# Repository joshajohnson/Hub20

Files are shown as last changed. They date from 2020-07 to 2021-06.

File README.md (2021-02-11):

# Hub20

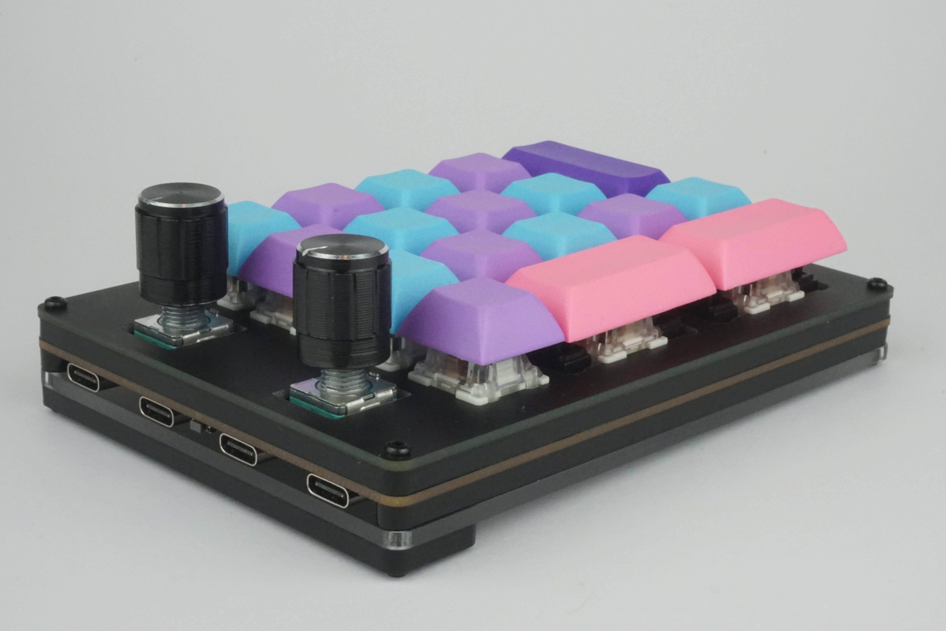
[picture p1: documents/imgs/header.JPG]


Hub20 is a numpad with a bunch of features you never knew you needed. They include:

- Left and Right handed layouts supported, along with a 4x5 1U grid enabling it to be used as a macropad.
- Two rotary encoders, enabling intuitive controls for a wide range of tools including CAD and photo / video editing.
- Inbuilt USB 2.0 Hub with Type-C connectors, allowing connection to other keyboards, memory sticks, wireless receivers and more!
- VIA and QMK compatibility, including a "macro" mode enabling the keys to be remapped on a host computer.
- 27 addressable RGB leds, including one under each key.

If this project looks familiar, it's because it contains all the best parts of [Hub16](https://github.com/joshajohnson/Hub16), with a few added extras.

## Project Status

Hardware is finalised and kits can be purchased from [Tindie](https://www.tindie.com/products/joshajohnson/hub20-programmable-macro-numberpad/).

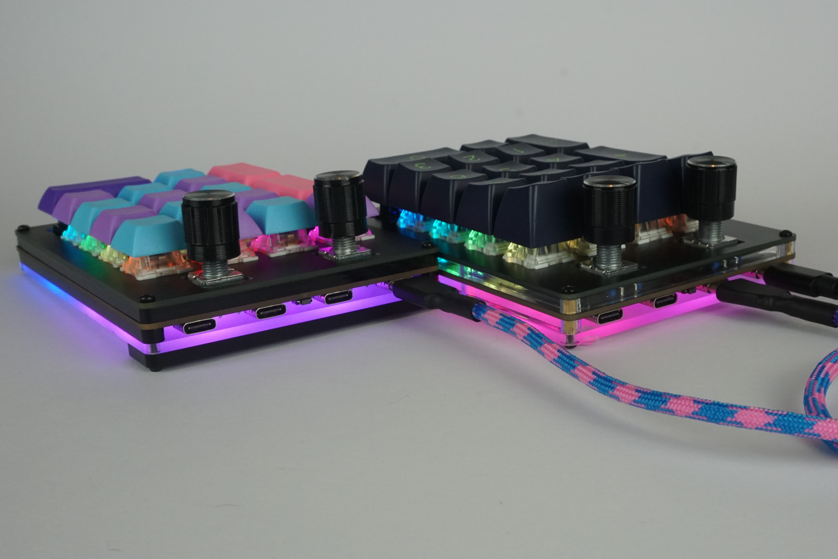
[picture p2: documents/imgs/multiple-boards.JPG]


## Getting Started Guide

- [Keyboard Assembly](documents/keyboard-assembly.md)
- [VIA Keymap Configuration](documents/via.md)
- [Macro Configuration](documents/macro.md)

## Detailed Info

- [Advanced Firmware / Software Configuration](documents/advanced-config.md)
- [PCB SMT Assembly Guide](documents/pcba.md)
- [Enclosure Manufacturing](documents/enclosure.md)

### Repo Contents

- `documents` contains all documentation and images for the project.
- `firmware` contains both the source and precompiled binaries for Hub20.
- `hardware` contains the KiCad design files for the keyboard.
- `josh-kicad-lib` is my personal KiCad parts library which contains many of the parts used.
- `scripts` contains a number of scripts used in the PCB design process.
- `mechanicals` contain the plate and case design for Hub20.
- `production` contains all the files required to produce the PCB. It also contains test scripts and jigs.
- `software` contains all the VIA config, along with template script to use Hub20 as a macropad with software on your computer.

### Notes on the USB Hub

The hub is a four port USB 2.0 Hub with Type-C connectors, aimed at allowing connection of keyboards, mice, memory sticks, wireless receivers, and other small devices (including a second Hub20!)  to your computer.

Due to cost and space constraints, the hub has some limitations. The hub **is not**:

- USB 3.x, Power Delivery, Thunderbolt, DisplayPort, etc compatible. 
- Designed to charge your phone quickly. Only 100mA is guaranteed per port.
- Designed to work with power hungry devices such as spinning hard drives.
- Guaranteed to provide full USB 2.0 speeds and performance on all ports.

Might you be able to charge your phone whilst copying files at full speed of a spinning hard drive over a long cable? Maybe. However Hub20 is a numpad first, USB hub second, so if you are looking for a high performance device I'd suggest picking up a dedicated USB hub and just using Hub20 as a numpad.

If you have any questions or comments please get in touch. I can be found on Discord as `_joshajohnson#9451`, [Twitter](https://twitter.com/_joshajohnson), email, or leave an issue or pull request on this repo.

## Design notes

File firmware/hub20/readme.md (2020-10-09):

# Hub20

Hub20 is a 20 key macro pad with an inbuilt USB 2.0 hub and dual rotary encoders. It can be configured to be a left / right hand numberpad, along with a 4x5 1u layout.

For more information regarding the keyboard, please visit the [Hub20 Website](https://www.joshajohnson.com/hub20-keyboard/) or [GitHub Repo](https://github.com/joshajohnson/Hub20).

* Keyboard Maintainer: [Josh Johnson](https://github.com/joshajohnson)
* Hardware Supported: Hub20 PCB (STM32F072)
* Hardware Availability: [Josh Johnson](https://www.joshajohnson.com/hub20-keyboard/)

Make example for this keyboard (after setting up your build environment):

    make hub20:default

See the [build environment setup](https://docs.qmk.fm/#/getting_started_build_tools) and the [make instructions](https://docs.qmk.fm/#/getting_started_make_guide) for more information. Brand new to QMK? Start with our [Complete Newbs Guide](https://docs.qmk.fm/#/newbs).

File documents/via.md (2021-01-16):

# VIA Keymap Configuration

`Hub20 was recently merged into VIA, so it should be automatically detected. If for some reason it is not, the below info should allow you to manually load the config file.`

- Open the settings tab in VIA, and enable "Show Design Tab".
- On the design tab, click "load" and select the [hub20.json](../software/via-hub20.json) file.
	- To download the json file, click through to the above link, select raw, copy all of the next into notepad or a similar text editor, and save as hub20.json.
- Hub20 should now be detected by VIA.

VIA is a great way to graphically configure your keyboard without going through the hassle of configuring build environments and poking around in the code.

## Install VIA

To use VIA, first [download and install](https://caniusevia.com/) the configuration software, and then plug in your keyboard. It should detect and show a graphic of Hub20 on your screen.

**Note: Hub20 ships with VIA by default, however if you have flashed a custom firmware on it you will need to ensure a VIA compatible keymap is on your board before continuing.**

## Configure Keys

From within VIA, you can easily configure keys as required. It allows not only the typical keys found on your keyboard, but media keys, macros, layer shifting to enable different functions per key, and even keys to control the LEDs installed in Hub20. It does not however allow you to configure the rotary encoder behaviour.

Due to the multiple layouts Hub20 allows, VIA allows you to toggle on / off the 2U keys required for it to be a left hand numpad. This can be done from the `layouts` tab in the top left of the screen. To configure Hub20 as a right hand numpad, enable split plus / enter / zero, and change the keymap as required. For the 2U keys, simply assign the same key to both keys in the pair.

## Configure Encoders

By default, the encoders are configured to volume up / down (left) and media next / prev (right).

Unfortunately, due to limitations in VIA the encoders are not visible or configurable. The best workaround at this time is to build a new VIA keymap with the encoder functions altered to suit your use case, flash this onto the board, and then configure the remainder of the keys in VIA. This can be done by following the below instructions:

- Follow the QMK [getting started guide](https://docs.qmk.fm/#/newbs_getting_started) to install the toolchain and configure your build environment.
- If you are reading this, the Hub20 firmware is not yet merged into QMK. Copy the `hub20` folder in `firmware` to `qmk_firmware/keyboards/hub20` before continuing.
- Open the `qmk_firmware/keyboards/hub20/keymaps/via/keymap.c` file in your preferred text editor.
- Locate the function `encoder_update_user`, and update the keycodes in `tap_code(KC_xxx)` to one from the [keycodes list](https://docs.qmk.fm/#/keycodes?id=basic-keycodes). If you use keycode not on the basic list, you may need to replace `tap_code` with `tap_code16`.
- With the changes made, save your new keymap, build, and flash the keymap to Hub20 with `make hub20:via:flash` run from the `qmk_firmware` directory.
- You should now see the encoders functioning as desired, and you can configure the remainder or your keyboard using VIA.

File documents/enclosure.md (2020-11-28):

# Enclosure Manufacturing

There are a number of ways the enclosure can be manufactured, and these options are outlined below:

All case files can be found in `mechanicals/1.0`.

By default, the enclosure has the below stackup:

```
--- PCB Plate, 1.6mm
--- Acrylic Upper, 4mm
--- Hub20 PCB, 1.6mm
--- Acrylic Mid, 4mm
--- Acrylic Lower, 3mm
  - Acrylic Incline, 3-4mm (optional)
```

You can however make a number of substitutions:

- Swap PCB plate for 3mm acrylic, and move upper 4mm acrylic to 3mm - note some switches may have reduced insertion depth into the PCB.
- Replace acrylic lower with FR4 PCB.
- 3d print parts instead of laser cutting or utilising PCBs for mechanical elements.
- Design your own! .step file can be exported from KiCad into you mCad tool of choice.

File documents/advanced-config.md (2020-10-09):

# Advanced Firmware and Software Configuration

This section details how Hub20 works, and how you can modify it to suit your needs.

If you are simply looking for into on how to get up and running, the [VIA](via.md) and [Macro](macro.md) documentation may be better suited.

## Summary

The macro functionality of Hub20 is quite unique, as it moves control over what key is detected by the host computer from the keyboard to the computer itself, which enables a whole new level of control. Examples of functionality enabled by this include:

- Dynamically assigning keys pressed depending on open application, e.g. encoder changing zoom in Photoshop, but zooming timeline in Premiere.
- Accessing low level functions, such as directly bringing a given application to the foreground without tabbing through open windows.
- Running shell commands without opening a shell and playing back key sequences.
- Any other feature that your software (AutoHotKey, Karabiner-Elements, Autokey) provides an interface for.

## Theory of Operation

- Hub20 works by presenting a uniquely identifiable key to your computer, which can be intercepted by a intermediate layer of software on your computer, and can then be processed as required.
- This works by "wrapping" a normal key press with a modifier key to create a unique key, just like pressing SHIFT changes the key shown on your screen when pressed in conjunction with a key on your keyboard.
- However, as CTRL, SHIFT, ALT etc are commonly used they would not be very helpful to generate a unique key, so we instead use F13 - F24 as most keyboards do not have these, but are still valid keycodes.
- To achieve this, when you press a key, Hub20 first sends a modifier key (e.g. F23) before pressing down the key you touched. Upon release of your key, it releases the modifier, allowing the computer to pick up that Hub20 has pressed a key.
- **NOTE** macOS instead uses the VID:PID of your device to uniquely identify Hub20, however the high level concept outlined above still applies.

## Firmware Configuration

The default configuration can be easily changed, allowing for further customisation of the board. Examples of what can be done include:

- Holding down a key / encoder button results in different keys being sent when rotating the encoder, effectively doubling (or tripling etc) the number of encoders on the board.
- Extending the number of macro keys by having multiple layers of unique keys, accessed by the bottom row of keys being dedicated to shifting layers.
- Building the macro configuration with VIA enabled, allowing LEDs to be customised from the VIA GUI instead of tapping keys to change the mode and colour.

Key sections of the code and their function are outlined below:

| Section | Description |
| --- | --- |
| `#define KC_WRAP` | If you have more than one Hub20 connected, change the wrapping function key to differentiate boards. |
| `const uint16_t PROGMEM keymaps` | This section is where the keymaps live, and if you want to alter the behaviour of a key this is the place to do it. |
| `void encoder_update_user` | Want to change what rotating an encoder does? If so this is the place to look. |
| `bool process_record_user` | Every time a non [quantum](https://docs.qmk.fm/#/keycodes?id=quantum-keycodes) key is pressed, it will be run throught this section, and is the place to implement custom functions such as sending custom strings, turning on / off a mouse shaker, or any custom action you want when a key is pressed. |
| `void td_ctrl` | To work around the limitations of `process_record_user` this function is required to ensure the layer toggle key is wrapped when sent to the host computer. If you don't want to use tap dance, or are okay having a dedicated key to toggling layers, this can be removed. |

## Software Configuration

Due to the different software being required for each OS, and the varying levels of options each tool provides, it's challenging to make any specific recommendations for ways to customise the software running on your host PC. With this said, I would strongly suggest looking at the `hub20-example.ahk` script which is an obfuscated version of what I use at work every day, along with the documentation of your chosen scripting tool to see what is possible, and think how it may help your day to day workflow. Below are some examples of what people have used their Hub16 / Hub20 to automate:

- Running complex shortcuts with a single key.
- Placing common shortcuts (enlarge / shrink) on the encoders to ease adjustment.
- Pulling a specific windows to the foreground with a single tap.
- Dedicated keys for video conference muting, sharing screens etc.
- Automating filling out of repetitive forms (e.g. the Auspost customs declaration...)
- Having emoticons or emoji a single keystroke away. (•◡•) /
- Alternate input for racing / flight simulators.

If you come up with a novel use case, I'd be very interested to hear about it so please get in touch!

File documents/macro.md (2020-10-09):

# Macro Configuration

Hub20 can also be used with software on your computer to enable powerful, context aware macros to be run.

This works by sending uniquely identifiable keys to your computer which are picked up by software, which can then map those keys as required. As such, this requires the correct firmware to be loaded onto Hub20, and software to be installed on your computer.

## Firmware

Hub20 does not ship with the macro firmware preinstalled, but is easily flashed onto your board.

MechMerlin has [a great video](https://youtu.be/VR53Wo9Z960) on the process, so I will highlight the Hub20 specific configurations / settings.

- When selecting the file to flash, use `firmware/binaries/hub20_macro.bin`.
- There is no need to select the microcontroller before flashing the board.
- The reset button can be found between the USB connectors on the back of the board, or by holding down the top right button and depressing the left encoder.

The default configuration for the keyboard is shown below:

```
------------------
|  ENC1   ENC2   |  ENC1:Clockwise: u
| a   b   c   d* |  ENC1:Anticlockwise: v
| e   f   g   h  |  ENC2:Button: w
| i   j   k   l  |  ENC2:Clockwise: x
| m   n   o   p  |  ENC2:Anticlockwise: y
| q   r   s   t  |  ENC2:Button: z
------------------
```

\* Once flashing the macro layout you may notice that holding or tapping the top right key quickly may not result in a key being sent. This because if you double tap that key, it will bring you to a configuration layer on the keyboard which allows you to control the LEDs and reset the keyboard.  Double tapping the same key will return you to the base layer. The keymap for this configuration is shown below:

```
                Reset,   _______,
 RGB On/Off,  RGB Prev,  RGB Next,       Home,
    _______,  Bright +,  BRIGHT -,    _______,
    _______,     Hue +,     Hub -,    _______,
    _______,     Sat +,     Sat -,    _______,
    _______,   _______,   _______,    _______,

```

## Software

### Windows

- Download and install [AutoHotKey](https://www.autohotkey.com/).
- Copy the example script from `software/hub20-template.ahk` into a folder of your choice.
- For the script to run at startup, I strongly suggest placing a shortcut to the above file in `%APPDATA%/Roaming/Microsoft/Windows/Start Menu/Programs/Start-up`.
- Configure the script to suit your use case, ensuring to restart the AHK script after each change, otherwise it will not use the latest changes.

### macOS

- Install [Karabiner-Elements](https://karabiner-elements.pqrs.org/docs/getting-started/installation/).
- Copy the example script from `software/karabiner-hub20.json` to your local `~.config/karabiner` folder.
- Configure keybindings as required.

### Linux

- Whilst it's slightly more painful and buggy to configure and use on Linux, the below is the best configuration I've got to work. PRs are very much welcome for improvements to this.
- Install AutoKey from [here](https://github.com/autokey/autokey/wiki/Installing#debian-and-derivatives), as the apt-get version is broken.
- Create a file in your home directory with the name `.Xmodmap` and the following contents

    ``` bash
    keycode 202 = Hyper_R
    add mod3 = Hyper_R
    ```

- Update xmodmap with `xmodmap ~/.Xmodmap` and then confirm that `mod3` has been updated by entering `xmodmap` in your shell and looking for `mod3 Hyper_R (0xca)`.
- Then add it to your ```~./bashrc```, as this will allow the keyboard to work **only after a shell is opened by the user**. A PR to resolve this would be very welcomed.
- Load the AutoKey files found in `software/hub16` and it should work.
    - Note: you may need to make a new folder from within Autokey, then copy your files in as it is particular about locating new files.
- You will also need to configure AutoKey to start at boot, which can be done from `Edit -> Preferences`.
- For volume and media control as configured in my example code, [playerctl](https://github.com/altdesktop/playerctl) and ```alsa-utils``` must be installed.

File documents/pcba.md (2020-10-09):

# PCB SMT Assembly Guide

I highly recommend assembling this board using solder paste, a stencil, and a reflow oven. If you don't have access to a reflow oven, a hot air gun will also get the job done. 

- Gerbers can be found in `production/1.0-prod/gerbers.zip` folder, and can be uploaded to your favourite PCB manufacturer.
- Most PCB houses will generate the solderpaste stencil from your copper layer, which can cause issues. As such I recommend uploading the stencil separately to ensure the apertures are as per the design files.
- The bill of materials can be found at `production/1.0-prod/bom.csv` and contains part numbers for all components on the board. DigiKey and LCSC part numbers are provided where available, however some parts such at the USB connectors, reverse mount LEDs, and USB hub may only be available at one or neither of the suppliers.
- The "Human PnP" file is located at `production/1.0-prod/assembly.html`, and will be very helpful in assembling the board.

With the board assembled and reflowed, it is time to power it up and flash the firmware.

- Before powering up, measure between 5V, 3V3 and GND to ensure there are no shorts. The capacitors either side of the linear regulator are an easy place to measure.
- Upon plugging the board in, you should see the PWR led turn on, and the USB hub enumerate. The STM32 microcontroller will not be detected at this time.
- To flash the firmware, run `make hub20:default:flash` from within your `qmk_firmware` folder. Reset the board using the reset button, and you should see `dfu-util` flash the board.
- Confirm all keys work by shorting the switch contacts with tweezers and looking for an output from the board, and confirm the USB hub works by plugging a device into each port and checking for enumeration. Ensure you flip the USB connector and test all the ports with it in the other orientation as well.

If the board does not work, common issues include:

- Shorts / opens on the QFN and USB footprints.
- Crystal for the USB hub not being soldered down correctly.
- Diodes being installed backwards.
- LEDs damaged due to moisture ingress / excessive heat during reflow.
- Shorts on the resistor networks.

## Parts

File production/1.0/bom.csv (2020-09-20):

Qty | Reference(s) | Value | Footprint | MPN | DigiKey | LCSC | Manufacturer | DNP | Notes | Substitue Allowed?
44 | C1, C11, C12, C13, C15, C16, C17, C21, C22, C23, C24, C25, C26, C27, C29, C30, C31, C33, C35, C36, C37, C38, C39, C4, C40, C42, C43, C46, C47, C48, C49, C5, C50, C51, C52, C53, C56, C58, C59, C6, C60, C7, C8, C9 | 100n | Capacitor_SMD:C_0603_1608Metric | CL10B104KB8NNNC | 1276-1000-1-ND | C1591 | Samsung Electro-Mechanics |  |  | Y - X5R or better
8 | C10, C19, C28, C32, C34, C54, C55, C57 | 1u | Capacitor_SMD:C_0603_1608Metric | CL10A105MP8NNNC | 1276-1866-1-ND | C29936 | Samsung Electro-Mechanics |  |  | Y - X5R or better
3 | C14, C20, C41 | 10u | Capacitor_SMD:C_0603_1608Metric | CL10A106MP8NNNC | 1276-1871-1-ND | C85713 | Samsung Electro-Mechanics |  |  | Y - X5R or better
1 | C18 | 4u7 | Capacitor_SMD:C_0603_1608Metric | CL10A475MP8NNNC | 1276-1905-1-ND | C307473 | Samsung Electro-Mechanics |  |  | Y - X5R or better
2 | C44, C45 | 15p | Capacitor_SMD:C_0603_1608Metric | CL10C150JB8NNNC | 1276-1296-2-ND | C1644 | Samsung Electro-Mechanics |  |  | Y - NP0 / C0G
1 | D1 | 1N4148 | Diode_SMD:D_SOD-123 | 1N4148W-7-F | 1N4148W-FDICT-ND | C83528 | Diodes Inc |  |  | Y - Any 1N4148
22 | D10, D11, D12, D13, D14, D16, D18, D19, D20, D21, D22, D24, D25, D26, D27, D28, D29, D4, D5, D6, D7, D8 | 1N4148 | Diode_SMD:D_SOD-123 | 1N4148W-7-F | 1N4148W-FDICT-ND | C83528 | Diodes Inc |  |  | Y - Any 1N4148
7 | D15, D17, D2, D23, D3, D30, D9 | WS2812B | LED_SMD:LED_WS2812B_PLCC4_5.0x5.0mm_P3.2mm | WS2812B | 1528-1104-ND | C114586 | Worldsemi |  | Must be black | N
20 | D31, D33, D34, D35, D36, D37, D38, D39, D40, D41, D42, D43, D44, D45, D46, D47, D48, D49, D50, D51 | SK6812MINI-E | josh-keyboard:DUMMY_SK6812MINI-E | SK6812MINI-E |  |  | Shenzhen LED Colour |  | Similar to: https://www.alibaba.com/product-detail/Best-selling-SK6812-MINI-E-1500pcs_62354369359.html | N
1 | D32 | LED | LED_SMD:LED_0603_1608Metric | OSK40603C1E |  | C268294 | OptoSupply |  |  | Y - Any Pink / Purple
1 | F1 | 1A | josh-passives-smt:Fuse_0805_2012Metric | 0805L100WR | F2774CT-ND | C80270 | Littelfuse |  |  | Y - 1A hold / >1.5A trip
3 | F2, F3, F4 | 500mA | josh-passives-smt:Fuse_0805_2012Metric | 0805L050WR | F2772CT-ND | C207022 | Littelfuse |  |  | Y - 500mA hold / 1A trip
5 | FB1, FB2, FB3, FB4, FB5 | 600R | josh-passives-smt:Ferrite_Bead_0603 | BLM18KG601SN1D | 490-5258-1-ND | C85833 | Murata |  |  | Y - 600R, > 1A current
4 | H1, H2, H3, H4 | M3 | MountingHole:MountingHole_3.2mm_M3 |  |  |  |  | DNP
4 | J1, J2, J3, J4 | USB_C_Receptacle_USB2.0 | josh-connectors:USB_C_U262-161N-4BVC11 | U262-161N-4BVC11 |  | C319148 | XKB Enterprise |  | Cannot source from DigiKey | Y - Footprint / pinout compatiable
1 | JP1 | LED | Jumper:SolderJumper-2_P1.3mm_Bridged_RoundedPad1.0x1.5mm |  |  |  |  | DNP
1 | LOGO1 | Josh-Details | josh-logos:josh-details |  |  |  |  | DNP
1 | LOGO2 | Board-Title | josh-logos:board-title |  |  |  |  | DNP
1 | LOGO3 | Josh-Logo | josh-logos:josh-johnson-logo-11x2 |  |  |  |  | DNP
1 | LOGO5 | OSHW | josh-logos:OSHW-Logo2_9.8x8mm_Mask |  |  |  |  | DNP
2 | MX1, MX2 | 2U | josh-keyboard:MXOnly-2U-NoLED-3PIN |  |  |  |  | DNP
4 | MX3, MX4, MX5, MX6 | 2U | josh-keyboard:MXOnly-2U-ReversedStabilizers-NoLED-3PIN |  |  |  |  | DNP
1 | Q1 | DTC123J | Package_TO_SOT_SMD:SOT-23 | DTC123JKAT146 | DTC123JKAT146CT-ND | C111724 | ROHM Semicon |  |  | Y - Any DTC123J
1 | Q2 | BSS138 | Package_TO_SOT_SMD:SOT-23 | BSS138 | BSS138CT-ND | C52895 | ON Semiconductor |  |  | Y - Any BSS138
1 | R10 | 649R | Resistor_SMD:R_0603_1608Metric | MCR03ERTF6490 | RHM649CFCT-ND | C403314 | Rohm Semiconductor |  | LCSC: Substitute PN | Y - Same spec
3 | R14, R2, R3 | 5K1 | Resistor_SMD:R_0603_1608Metric | CR0603-JW-512ELF | 118-CR0603-JW-512ELFCT-ND | C14677 | Bourns |  | LCSC: Substitute PN | Y - Same spec
1 | R4 | 100K | Resistor_SMD:R_0603_1608Metric | CR0603-JW-104ELF | CR0603-JW-104ELFCT-ND | C100048 | Bourns |  | LCSC: Substitute PN | Y - Same spec
5 | R5, R6, R7, R8, R9 | 10K | Resistor_SMD:R_0603_1608Metric | CR0603-JW-103ELF | CR0603-JW-103ELFCT-ND | C144116 | Bourns |  | LCSC: Substitute PN | Y - Same spec
2 | RN1, RN2 | 10K | Resistor_SMD:R_Array_Convex_4x0603 | RAVF164DJT10K0 | RAVF164DJT10K0CT-ND | C107374 | Bourns |  | LCSC: Substitute PN | Y - Same spec
1 | RN3 | 10K | Resistor_SMD:R_Array_Convex_4x0603 | RAVF164DJT10K0 | RAVF164DJT10K0CT-ND | C107374 | Bourns |  | LCSC: Substitute PN | Y - Same spec
1 | SW1 | EVQPUL | josh-buttons-switches:Panasonic_EVQPUL_EVQPUC | EVQ-PUL02K | P10853SCT-ND | C397351 | Panasonic |  | LCSC: Substitute PN | Y - Same footprint
20 | SW10, SW11, SW12, SW14, SW15, SW16, SW17, SW18, SW19, SW2, SW20, SW21, SW22, SW23, SW3, SW4, SW5, SW6, SW8, SW9 | MX_RGB | josh-keyboard:MX_KEYSWITCH_RGB |  |  |  |  | DNP
2 | SW13, SW7 | EC11 | josh-buttons-switches:RotaryEncoder_Alps_EC11E-Switch_Vertical_H20mm_CircularMountingHoles | PEC11L-4120F-S0020 | PEC11L-4120F-S0020-ND |  | Bourns | DNP | Similar to: https://www.aliexpress.com/item/32839106848.html | Y - 20 pulse per revolution
1 | U1 | AP2112K-3.3 | Package_TO_SOT_SMD:SOT-23-5 | AP2112K-3.3TRG1 | AP2112K-3.3TRG1DICT-ND | C51118 | Diodes Incorporated |  |  | N
4 | U2, U6, U7, U8 | USBLC6-2SC6 | Package_TO_SOT_SMD:SOT-23-6 | USBLC6-2SC6 | 497-5235-1-ND | C7519 | STMicroelectronics |  |  | N
1 | U3 | STM32F072C8Tx | Package_QFP:LQFP-48_7x7mm_P0.5mm | STM32F072C8T6 | 497-17359-1-ND | C80488 | STMicroelectronics |  |  | N
1 | U5 | CY7C65632-28LTXCT | josh-dfn-qfn:QFN-28-1EP_5x5mm_P0.5mm_EP3.35x3.35mm_ThermalVias | CY7C65632-28LTXCT | 428-3156-1-ND | C466886 | Cypress Semiconductor |  |  | N
1 | Y1 | 12MHz | josh-oscillators:Crystal_SMD_3225-4Pin_3.2x2.5mm | ABM8-12.000MHZ-12-B1U-T | 535-14962-6-ND | C164041 | Abracon LLC |  | LCSC: Substitute PN | Y - 12 MHz, 10/12pF

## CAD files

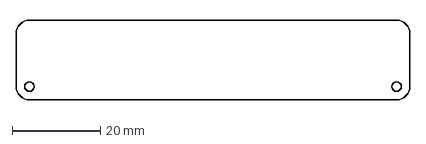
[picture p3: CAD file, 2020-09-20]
mechanicals/1.0/Hub20-riser.dxf
89.0 x 18.0 mm

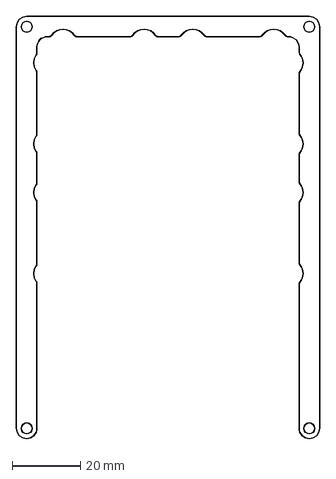
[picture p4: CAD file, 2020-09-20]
mechanicals/1.0/Hub20-mid.dxf
89.0 x 124.0 mm

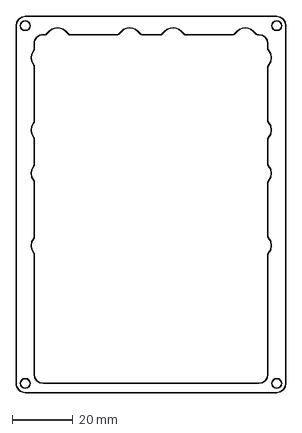
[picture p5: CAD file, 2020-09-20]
mechanicals/1.0/Hub20-top.dxf
89.0 x 124.0 mm

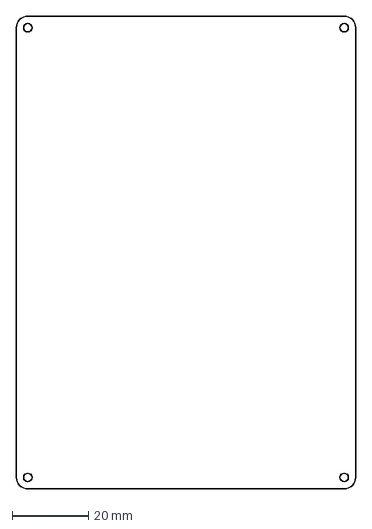
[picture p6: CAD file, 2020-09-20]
mechanicals/1.0/Hub20-bottom.dxf
89.0 x 124.0 mm

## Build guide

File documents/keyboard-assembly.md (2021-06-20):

# Assembly Instructions

Before assembling the board, ensure you have all of the required parts.

* Top cover / Plate PCB
* Assembled keyboard PCB
* Laser cut acrylic - 4 pieces
* 2 * Rotary encoders (20mm recommended)
* 2 * Rotary encoder knobs
* 4 * 4mm M2 cap head bolts (bare-bones 8 * 4mm)
* 4 * 8mm M2 cap head bolts (plus 2 * 10mm M2 if using bottom riser)
* 4 * 8mm female threaded standoffs (bare-bones 10mm)
* 4 * Rubber feet (optional)
* 17-20 * Cherry MX Key Switches (not shown) (3 pin switches required for 2U keys)
* 17-20 * 1U Cherry MX Keycaps (not shown)
* 0-3 * Screw In Stabilisers (not shown)

You will also require the following:

* Soldering iron and solder
* 1.5mm allen key
* Dielectric Grease (to lube stabilisers)

If you are assembling the bare-bones version, follow the below steps but omit the acrylic parts.

Please ensure you remove the protective paper off all acrylic parts before starting.
If there are rough edges on the PCB, feel free to smooth down with sandpaper or a file.

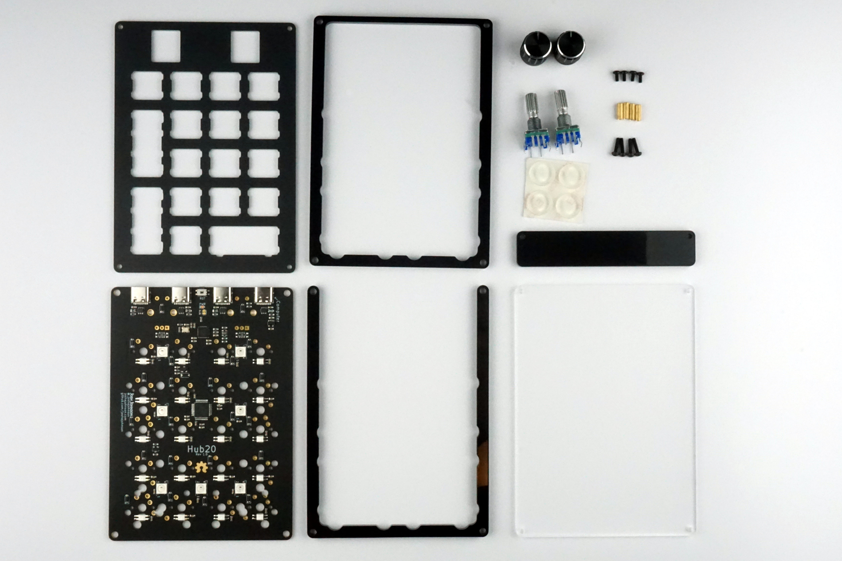
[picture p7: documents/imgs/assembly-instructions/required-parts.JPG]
Parts Required


### Step 0: Check PCB

Whilst we do our best to ensure the PCBs work, there may be issues that slip through QC or the boards may be damaged in freight. As such you should test the PCB before continuing.

Boards come preloaded with VIA for testing, and using their "Key Tester -> Test Matrix" option is the easiest way to ensure the board works. `If VIA does not automatically detect your HUb20, follow ` [these](via.md) `instructions to load the config file so the board can be detected.`

**Check the key switches by using tweezers to short the key switch pins together.**  
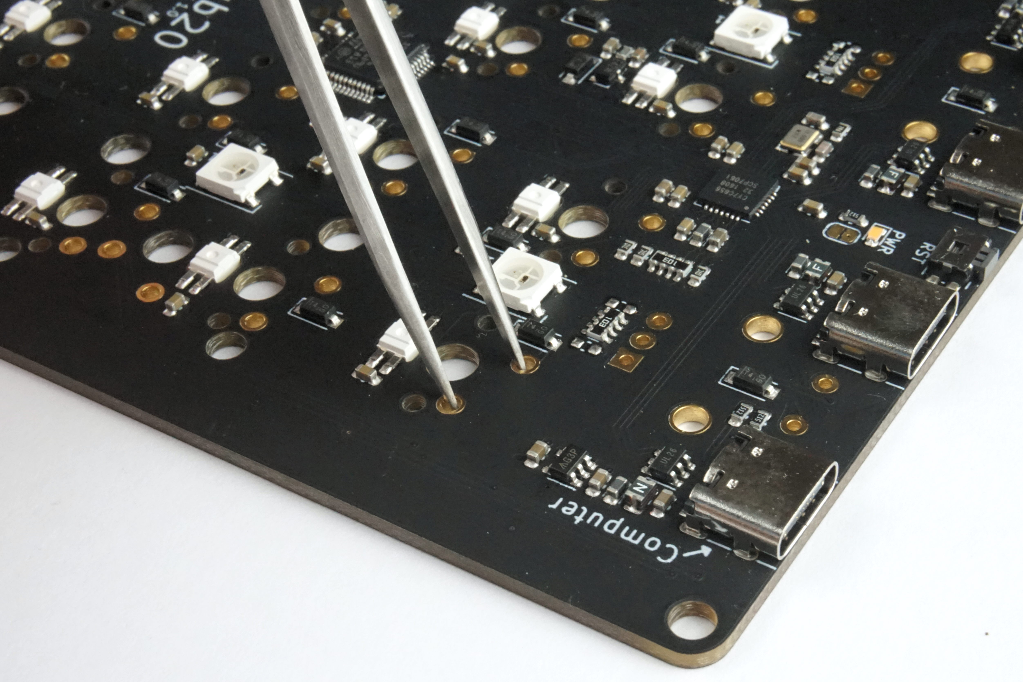
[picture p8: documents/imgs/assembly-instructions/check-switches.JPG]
Checking Keys


**Check the encoders by placing encoder against pins and rotating.**  
You may need to angle the encoder down to ensure it has good contact. Also test the encoder switch by shorting the two pins towards the top of the PCB.

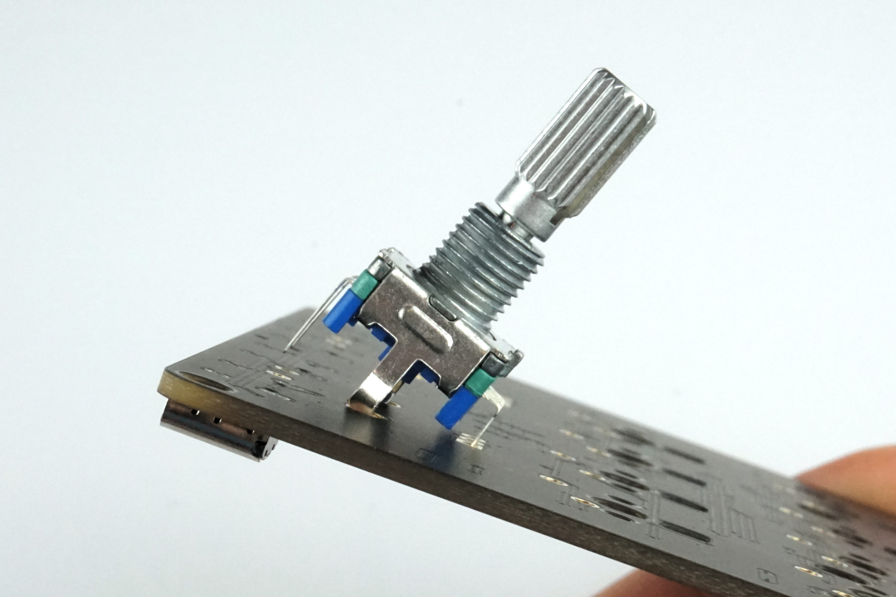
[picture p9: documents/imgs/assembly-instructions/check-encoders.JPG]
Checking Encoders


**Check the USB hub by connecting a device to each port, with cable orientated in both orientations.**  
You should see a your device appear on each port.

### **If there are any issues getting the above to work, please get in touch before proceeding to assemble the board.**

### Step 1: Solder Encoders

The first step in assembling your Hub20 is to solder the rotary encoders. Ensuring the pins are straight, insert the rotary encoders and tack in two pins on opposite corners.
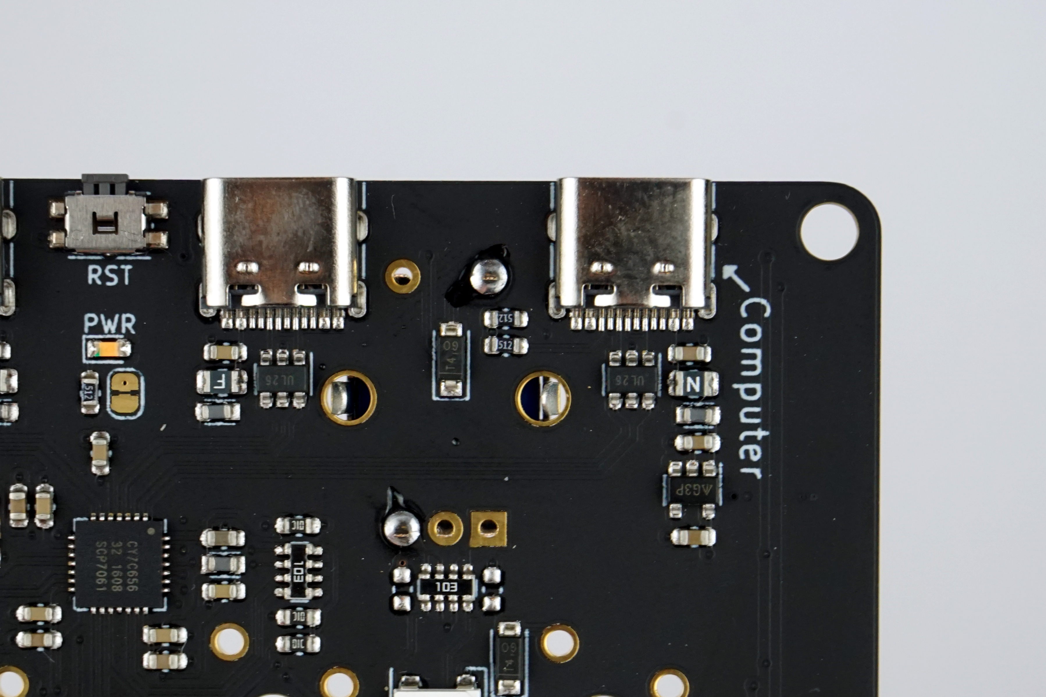
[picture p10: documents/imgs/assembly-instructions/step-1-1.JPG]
Tacking encoder


Before soldering in the remaining pins, ensure the encoder is perpendicular. If adjustments are required, heat one of the solder joints and gently push the encoder until it is seated. Repeat until you are satisfied with how the encoders look. (Hint: you shouldn't be able to see the encoder hiding on the other side of the board!)
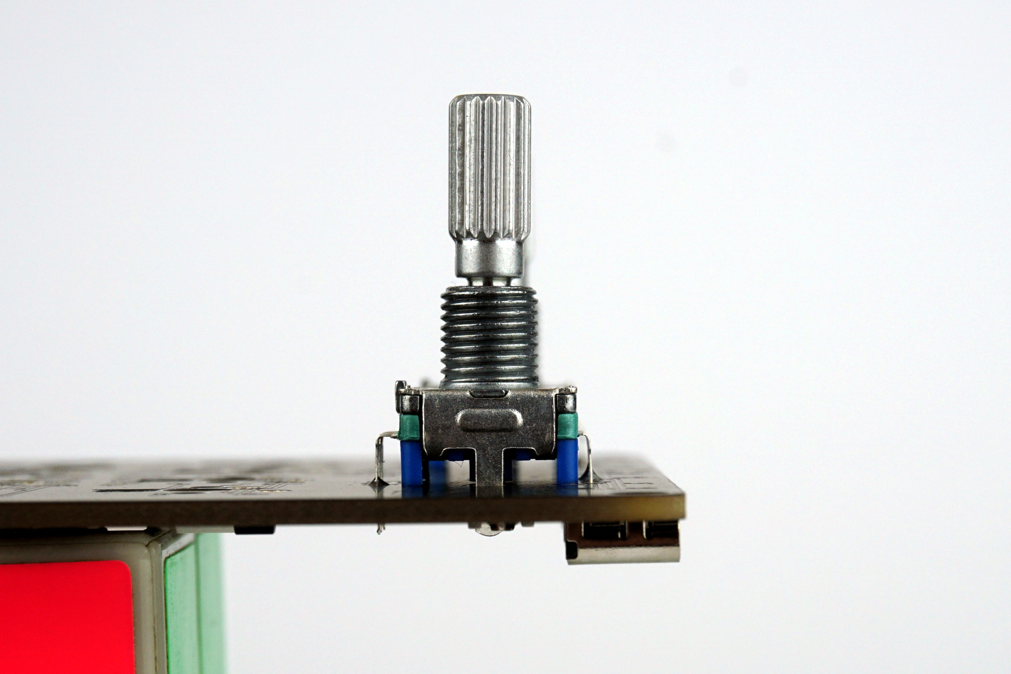
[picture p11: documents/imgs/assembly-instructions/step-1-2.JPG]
Checking encoder is square


With your encoders in nice and square, solder the rest of the pins. I'd suggest soldering all of the smaller pins and checking everything is still square before soldering in the mechanical legs as they make it very hard to move the encoder.
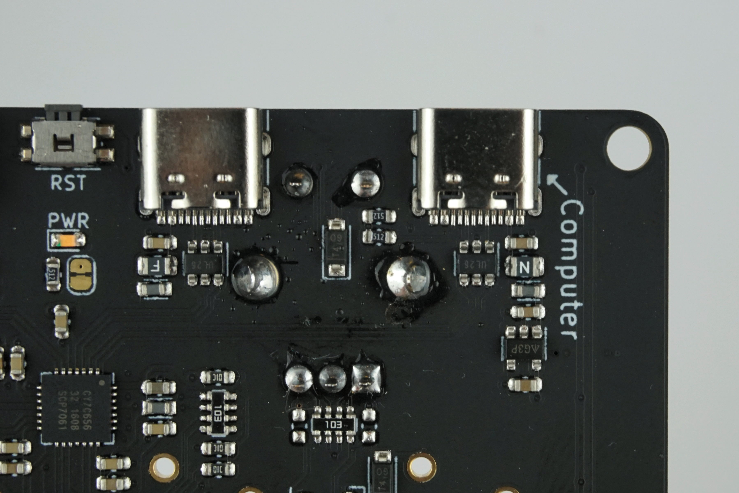
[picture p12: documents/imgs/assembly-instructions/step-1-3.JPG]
Soldering all pins


### Step 2: Install Stabilisers

Stabilisers are required for all of the "2U" switches, as they prevent the keys from wobbling. Before installing, I highly recommend you [lubricate your stabilisers](https://youtu.be/cD5Zj-ZgMLA) as otherwise they will rattle. If you don't want to go through the hassle of the above video, just make sure you [lube the wires](https://youtu.be/cD5Zj-ZgMLA?t=185) as this is the largest contributor to noise.

Depending on if you configure the board as a left or right numpad (or a 4x5 grid, in which case you can skip this) you will need to place the stabilisers in different locations. Left image is for the left numpad config, right image is for the right numpad configuration.

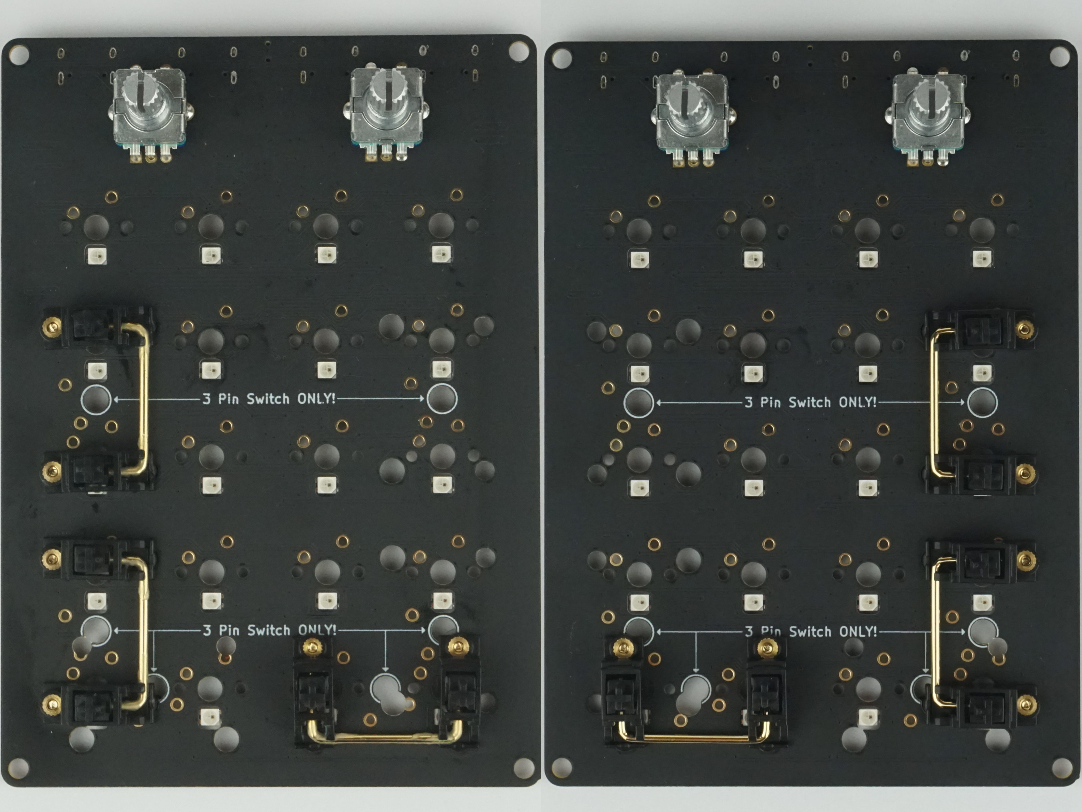
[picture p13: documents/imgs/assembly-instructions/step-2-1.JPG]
Stabiliser locations


When installing the stabilisers, ensure you use the non-conductive washers which are included. This prevents the screws from contacting with the PCB and causing shorts or damaging traces.

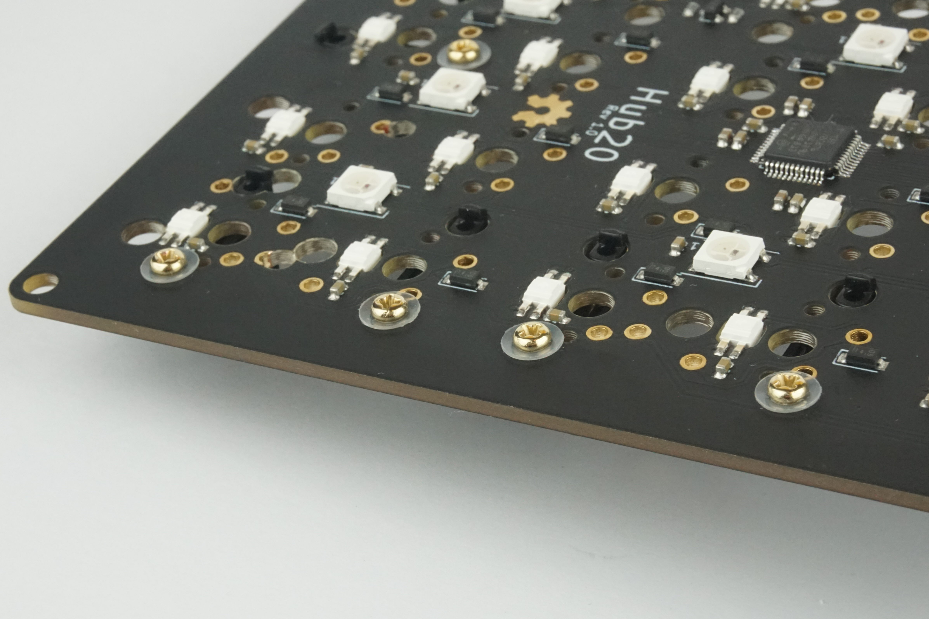
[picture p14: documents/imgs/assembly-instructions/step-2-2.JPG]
Ensure you use non-conductive washers


### Step 3: Assemble upper case

With the encoders soldered and stabilisers installed, the next step is to thread the standoffs into the shorter screws through the top plate. Just do this up touch tight, as we may need to loosen it later.
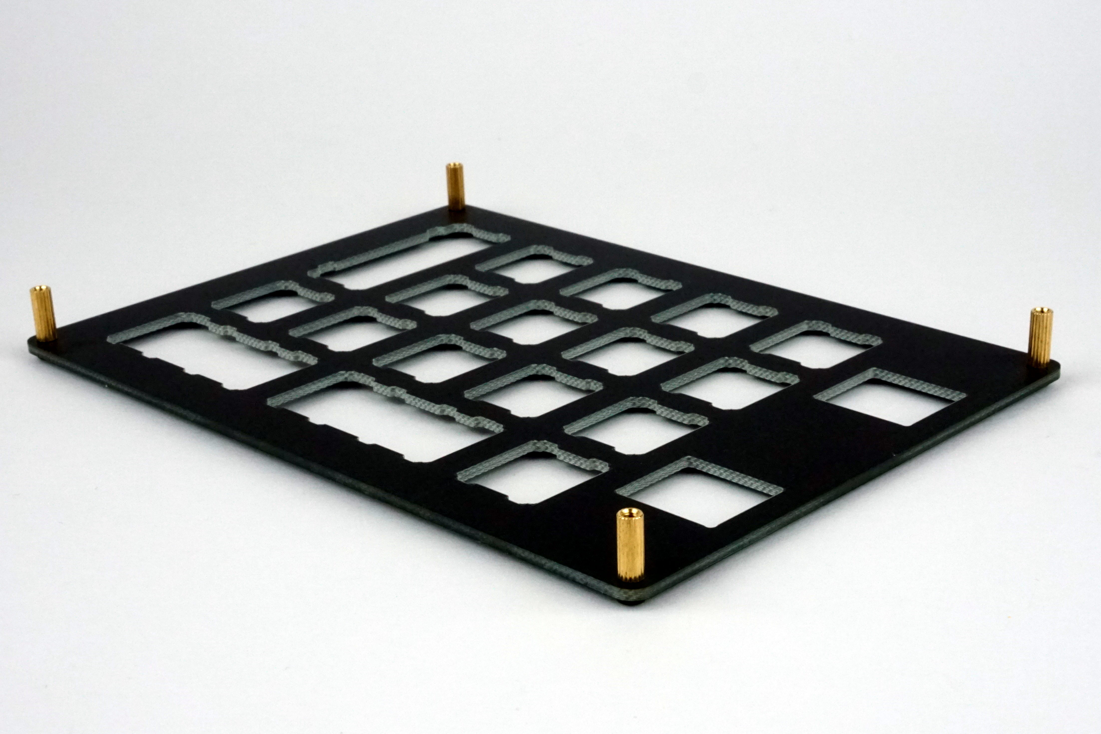
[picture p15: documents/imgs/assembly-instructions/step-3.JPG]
Bottom plate assembly


### Step 4: Add "O" shaped spacer

Add the "O" shaped spacer, ensuring the cutouts are towards the bottom as they provide clearance for the stabilisers.
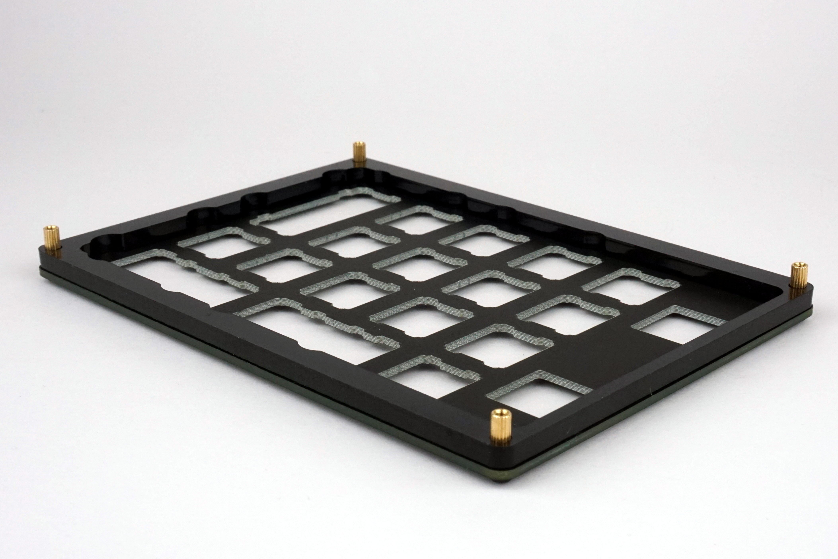
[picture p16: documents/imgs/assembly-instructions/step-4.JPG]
Adding U shaped spacer


### Step 5: Place PCB into case, and solder switches

Place the PCB into the case, followed by a switch in each corner to hold it in place.
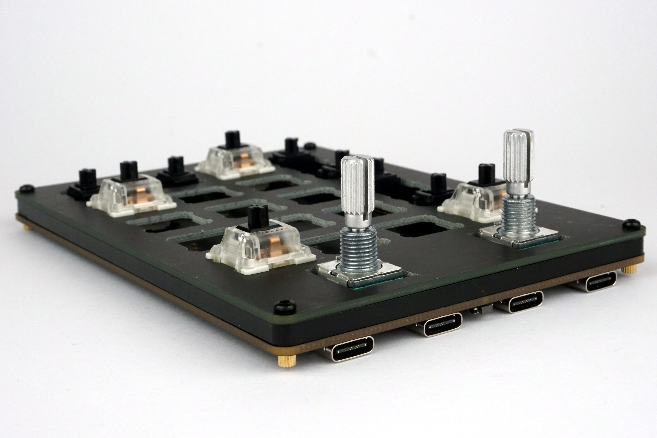
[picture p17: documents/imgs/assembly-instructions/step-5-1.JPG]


Tack one pin from each switch in place to keep everything together, and check for gaps along the side of the case. If there are gaps, press the case together whilst heating the soldered pin and the case should squish together. Once everything is flush, add the remaining keys and solder.
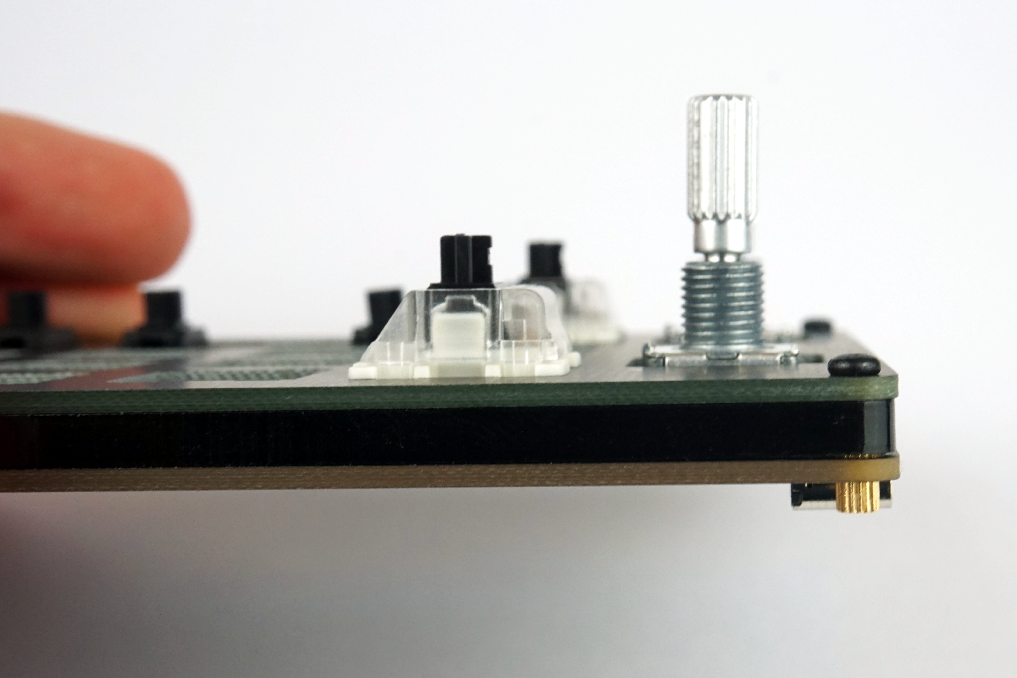
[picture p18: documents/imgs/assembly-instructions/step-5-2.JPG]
Checking edges are aligned


### Step 6: Add "U" shaped spacer

Place the remaining "U" shaped acrylic spacer on top of the PCB, ensuring the open end faces towards the USB connectors.
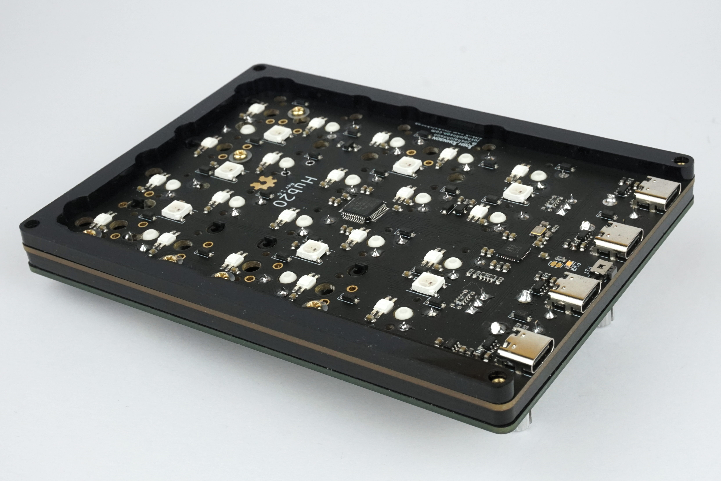
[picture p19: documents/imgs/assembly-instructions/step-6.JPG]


### Step 7: Add bottom plate and remaining screws

When installing the bottom plate, if you choose to use the small riser you will need to use the 10mm bolts instead of the 8mm bolts that are used at the bottom of the case. It can help to have the standoff flush to the acrylic to get the bolt started (please pretend the standoff is flush in this photo, I couldn't get a good photo of it...).
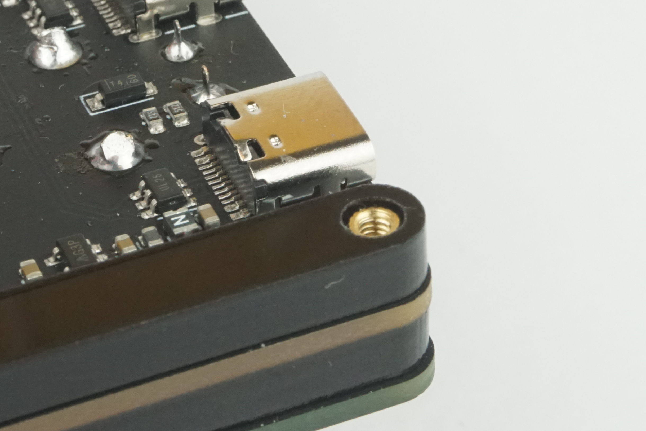
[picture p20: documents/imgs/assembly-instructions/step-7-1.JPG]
Spacer sitting flush


After installing the bottom plate and screws, snug all of the bolts up and your Hub20 is now assembled!
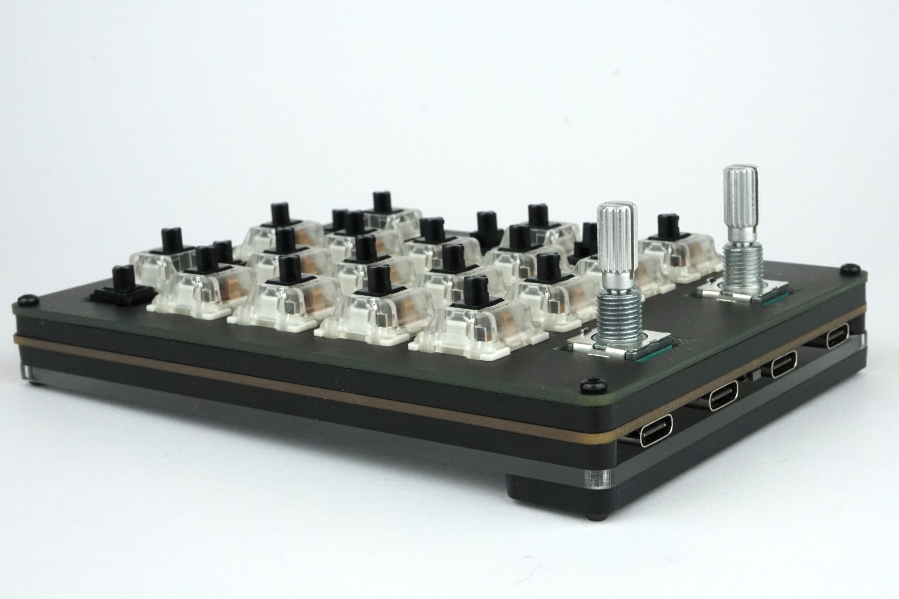
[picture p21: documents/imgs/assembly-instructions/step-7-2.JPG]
Bottom plates assembled


### Step 8: Add keycaps and encoder knobs

Finally, fit your keycaps of choice and the encoder knobs, and you are done! Enjoy :D
Adding knobs and keycaps

## Disabling Power LED

If you find the power LED annoying and would like to disable it, cut the jumper near the USB ports. The easiest way to do this is to run a knife down the thin black gap between the two large pads. The LED can be re-enabled by soldering the jumper shut.

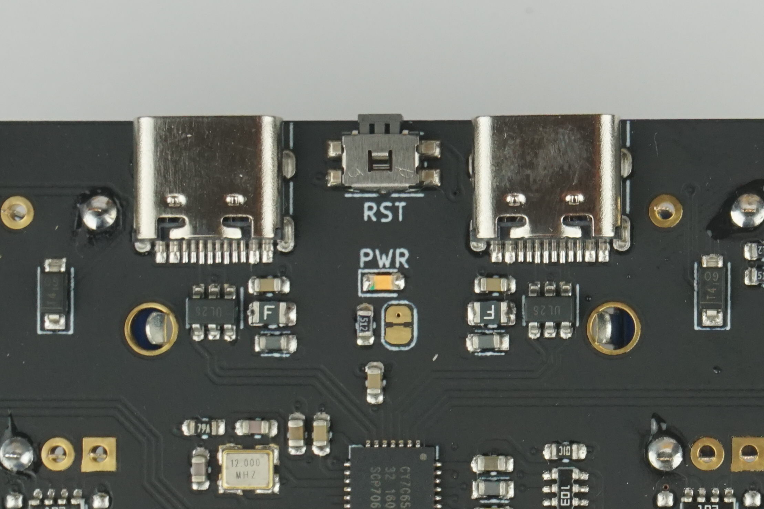
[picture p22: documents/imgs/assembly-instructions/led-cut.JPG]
Cutting trace for power LED


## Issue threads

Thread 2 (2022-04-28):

How simple would it be for a somewhat tech-aware beginner to mod this with a third encoder?

arrowtype, 2022-04-28:
Hi Josh, this is an incredibly cool project! It’s _so_ close to being my dream numpad, but I would love to find (or make?) something with _three_ encoders.

I’m a total noob in this area, but very curious how big a challenge it might be to learn the requisite software & processes to add a third encoder to the system.

My main reason for seeking three encoders is the software I use to kern fonts. It would be amazing to use one encoder to step through a list of letter pairs, a second to make large-grained adjustments, and a third to make fine-grained adjustments. I’ve tried to process with a two-encoder board, and it’s very nice, but I wish I didn’t have to toggle modes to go from large to small adjustments.

Thanks for making and sharing this project!

(PS: Apologies if this is the wrong place to ask, but I figure at least others might come across it if they search for a similar question.)

joshajohnson, 2022-04-28:
Hey Stephen,

Adding a third encoder would be easy if it wasn't for the USB hub being in the way.

The below image shows the two encoders on either side of the PCB, with the USB hub and associated hardware in the middle.

If you were willing to remove the USB hub, or change the mechanical dimensions of the board it would be feasible to add a third encoder, but doing that whilst keeping the same form factor would be very challenging if not impossible.

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

Another issue is that both the micro controller and USB hub used on this board are near impossible to purchase due to supply shortages these days, so you'd want to order the parts before going to the effort of redesigning the PCB.

As you can probably guess from the above I wouldn't recommend going down this path, but if you want to give it a go / or design a dedicated board with just three encoders and a pro micro or similar controller feel free to give me a yell if I can lend a hand.

Cheers

arrowtype, 2022-04-30:
This is amazing; thank you so much for the insights, Josh!

I do think I'd be willing to give up the usb hub in favor of a third encoder, but I hadn't considered the (obvious, in hindsight) issue of supply constraints. So, I'll look to solve that issue, and maybe once I can get those, I'll try my hand at KiCad. I may indeed give a shout if I reach that stage. (And if you ever need font/typographic insights, I'd be happy to reciprocate!)

Cheers!

Closed 2022-05-01.

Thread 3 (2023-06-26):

Lefties edition

chatelao, 2023-06-26:
Situation:
- My wife is a lefty/southpaw and I would like to make her a NumPad.

Wish:
- She would like a 100% mirrored version of the usual layout.

Idea:
- Is it possible to modify the NumPad to be similar to the Lotus58 a 100% flippable?
- This would allow me to make 5 NumPads, Lefty or Righty, from one PCB order.

joshajohnson, 2023-06-28:
Hi, the images show the numpad configured in what I believe to be a southpaw layout, can you check the layout and let me know what your desired layout would be?

The board can be configured to be left / right / 1U or any combination in between, so I'd like to think it meets your requirements out of the box.

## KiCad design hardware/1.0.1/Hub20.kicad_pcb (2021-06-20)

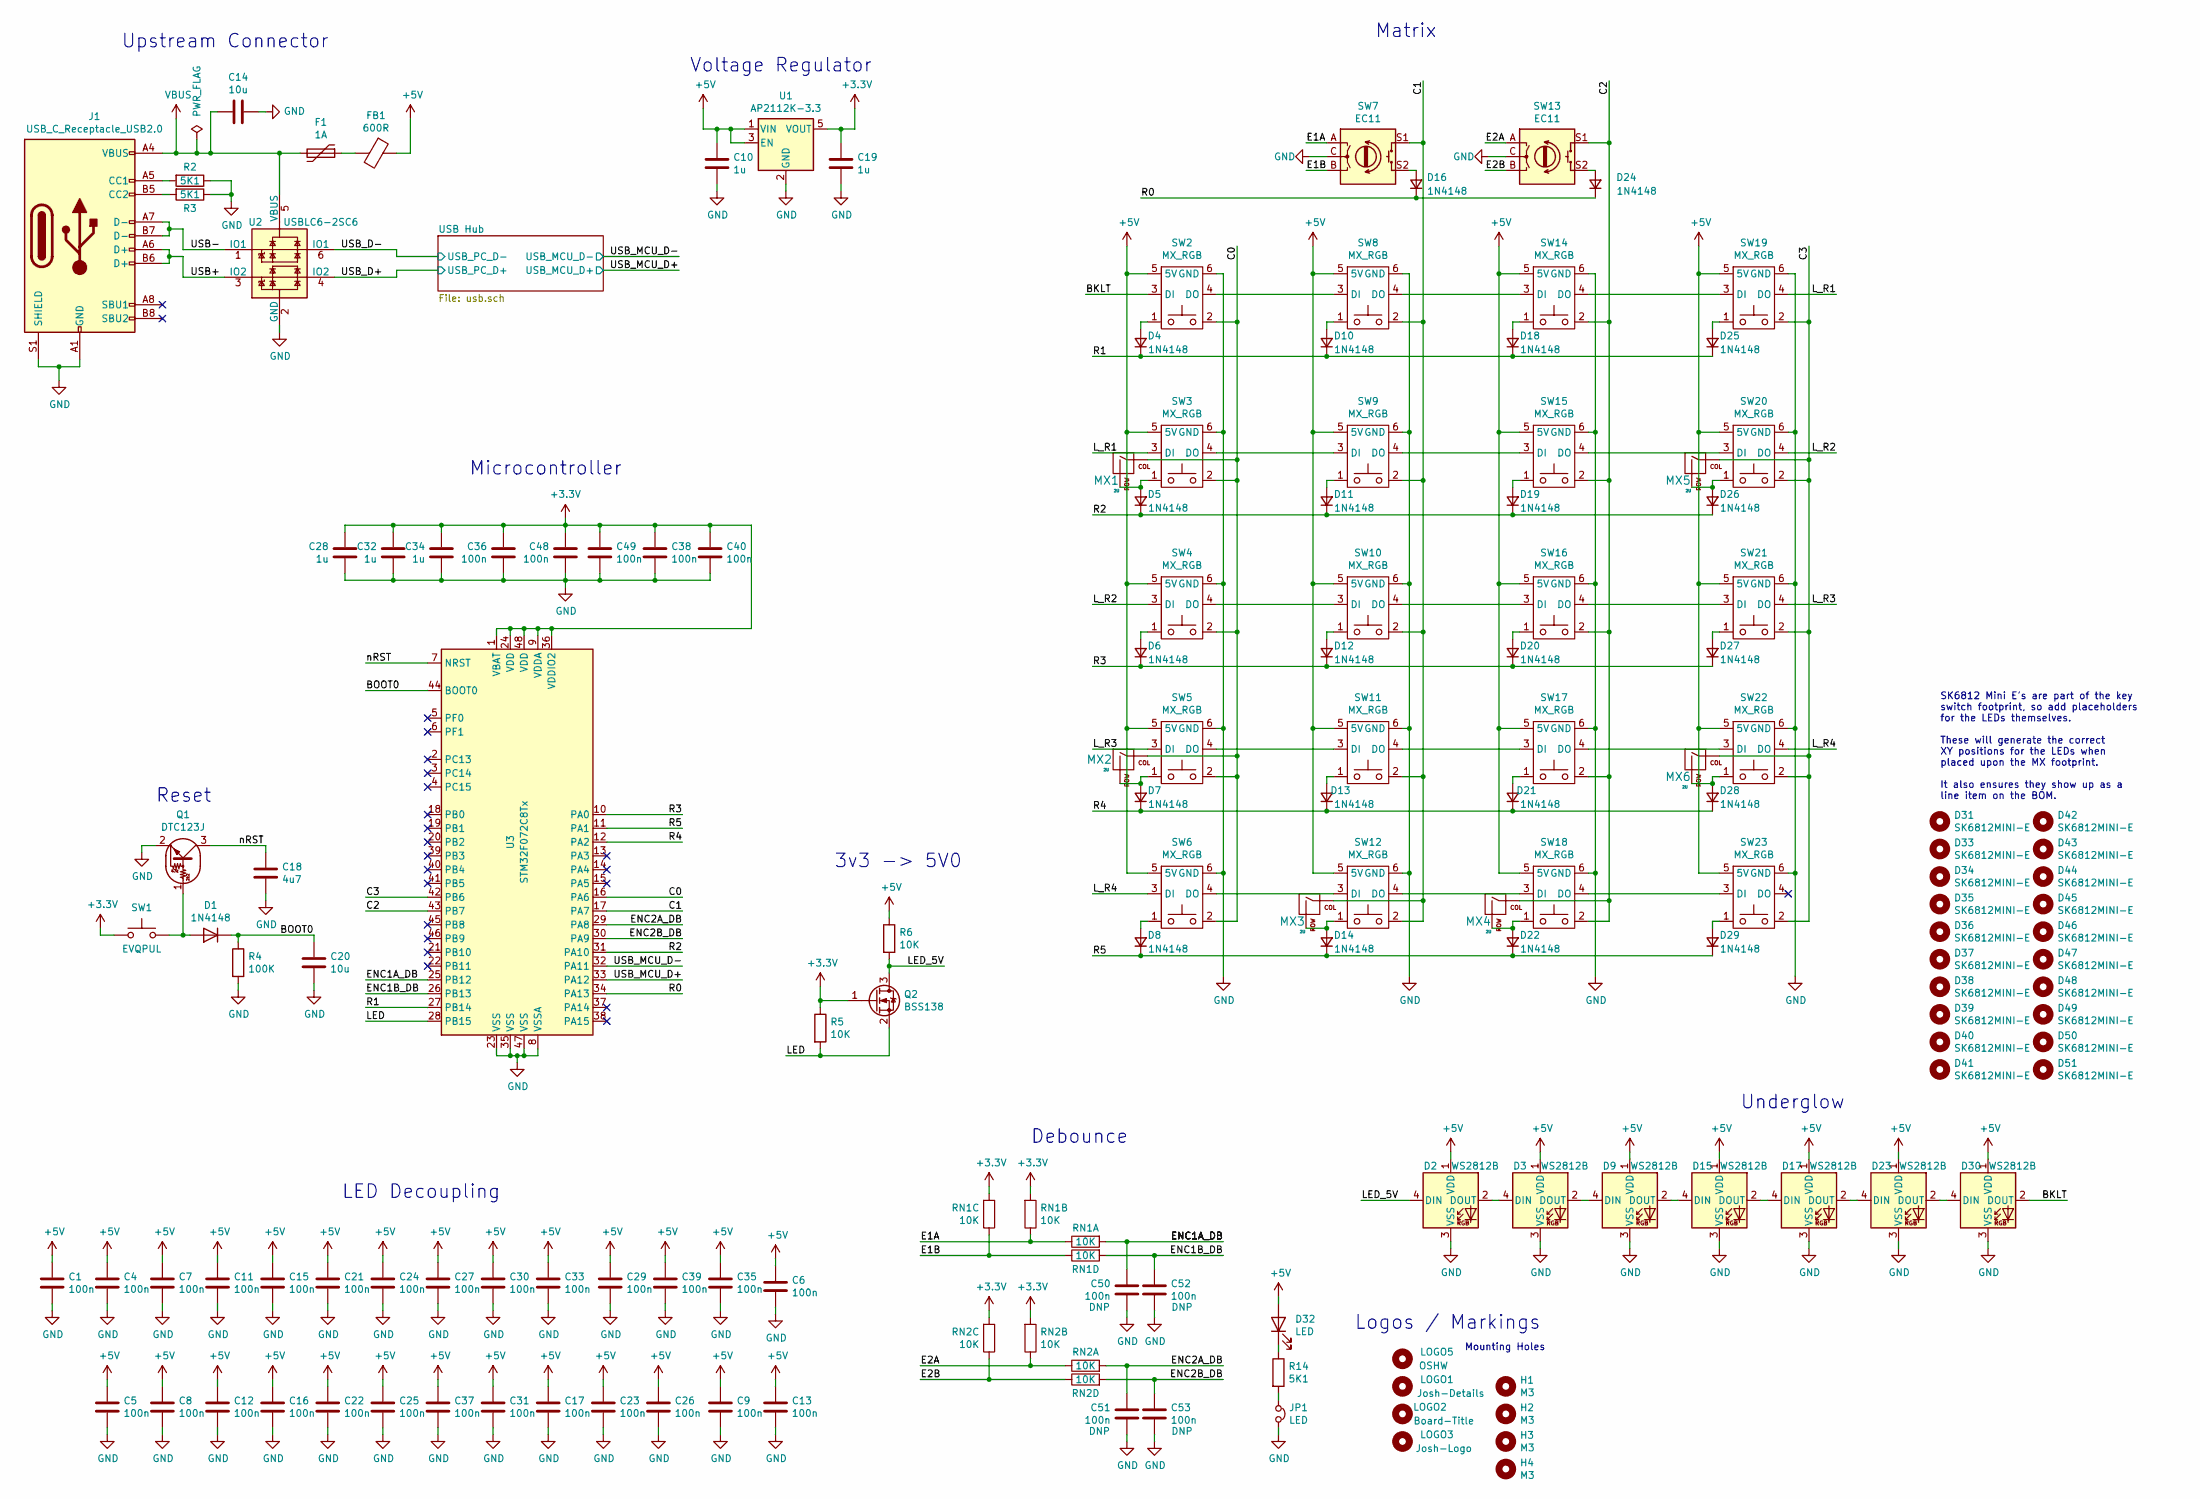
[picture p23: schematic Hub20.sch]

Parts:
C1, C4, C5, C6, C7, C8, C9, C11, C12, C13, C15, C16, C17, C21, C22, C23, C24, C25, C26, C27, C29, C30, C31, C33, C35, C36, C37, C38, C39, C40, C48, C49, C50, C51, C52, C53: 100n; C_0603_1608Metric; MPN CL10B104KB8NNNC; DigiKey 1276-1000-1-ND
C10, C19, C28, C32, C34: 1u; C_0603_1608Metric; MPN CL10A105MP8NNNC; DigiKey 1276-1866-1-ND
C14, C20: 10u; C_0603_1608Metric; MPN CL10A106MP8NNNC; DigiKey 1276-1871-1-ND
C18: 4u7; C_0603_1608Metric; MPN CL10A475MP8NNNC; DigiKey 1276-1905-1-ND
D1, D4, D5, D6, D7, D8, D10, D11, D12, D13, D14, D16, D18, D19, D20, D21, D22, D24, D25, D26, D27, D28, D29: 1N4148; D_SOD-123; MPN 1N4148W-7-F; DigiKey 1N4148W-FDICT-ND
D2, D3, D9, D15, D17, D23, D30: WS2812B; LED_WS2812B_PLCC4_5.0x5.0mm_P3.2mm; MPN WS2812B; DigiKey 1528-1104-ND
D31, D33, D34, D35, D36, D37, D38, D39, D40, D41, D42, D43, D44, D45, D46, D47, D48, D49, D50, D51: SK6812MINI-E; DUMMY_SK6812MINI-E; MPN SK6812MINI-E
D32: LED; LED_0603_1608Metric; MPN OSK40603C1E; LCSC C268294
F1: 1A; Fuse_0805_2012Metric; MPN 0805L100WR; DigiKey F2774CT-ND
FB1: 600R; Ferrite_Bead_0603; MPN BLM18KG601SN1D; DigiKey 490-5258-1-ND
H1, H2, H3, H4: M3; MountingHole_3.2mm_M3
J1: USB_C_Receptacle_USB2.0; USB_C_U262-161N-4BVC11; MPN U262-161N-4BVC11; LCSC C319148
JP1: LED; SolderJumper-2_P1.3mm_Bridged_RoundedPad1.0x1.5mm
LOGO1: Josh-Details; josh-details
LOGO2: Board-Title; board-title
LOGO3: Josh-Logo; josh-johnson-logo-11x2
LOGO5: OSHW; OSHW-Logo2_9.8x8mm_Mask
MX1, MX2: 2U; MXOnly-2U-NoLED-3PIN
MX3, MX4, MX5, MX6: 2U; MXOnly-2U-ReversedStabilizers-NoLED-3PIN
Q1: DTC123J; SOT-23; MPN DTC123JKAT146; DigiKey DTC123JKAT146CT-ND
Q2: BSS138; SOT-23; MPN BSS138; DigiKey BSS138CT-ND
R2, R3, R14: 5K1; R_0603_1608Metric; MPN CR0603-JW-512ELF; DigiKey 118-CR0603-JW-512ELFCT-ND
R4: 100K; R_0603_1608Metric; MPN CR0603-JW-104ELF; DigiKey CR0603-JW-104ELFCT-ND
R5, R6: 10K; R_0603_1608Metric; MPN CR0603-JW-103ELF; DigiKey CR0603-JW-103ELFCT-ND
RN1, RN2: 10K; R_Array_Convex_4x0603; MPN RAVF164DJT10K0; DigiKey RAVF164DJT10K0CT-ND
SW1: EVQPUL; Panasonic_EVQPUL_EVQPUC; MPN EVQ-PUL02K; DigiKey P10853SCT-ND
SW2, SW3, SW4, SW5, SW6, SW8, SW9, SW10, SW11, SW12, SW14, SW15, SW16, SW17, SW18, SW19, SW20, SW21, SW22, SW23: MX_RGB; MX_KEYSWITCH_RGB
SW7, SW13: EC11; RotaryEncoder_Alps_EC11E-Switch_Vertical_H20mm_CircularMoun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; MPN PEC11L-4120F-S0020; DigiKey PEC11L-4120F-S0020-ND
U1: AP2112K-3.3; SOT-23-5; MPN AP2112K-3.3TRG1; DigiKey AP2112K-3.3TRG1DICT-ND
U2: USBLC6-2SC6; SOT-23-6; MPN USBLC6-2SC6; DigiKey 497-5235-1-ND
U3: STM32F072C8Tx; LQFP-48_7x7mm_P0.5mm; MPN STM32F072C8T6; DigiKey 497-17359-1-ND

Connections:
+3V3: C19.1, C28.1, C32.1, C34.1, C36.1, C38.1, C40.1, C48.1, C49.1, Q2.1 (G), R5.1, RN1.2, RN1.3, RN2.2, RN2.3, SW1.1, U1.5 (VOUT), U3.1 (VBAT), U3.9 (VDDA), U3.24 (VDD), U3.36 (VDDIO2), U3.48 (VDD)
/BKLT: D30.2 (DOUT), SW2.3 (DI)
/BOOT0: C20.1, D1.1 (K), R4.1, U3.44 (BOOT0)
/C0: MX1.1 (COL), MX2.1 (COL), SW2.2, SW3.2, SW4.2, SW5.2, SW6.2, U3.16 (PA6)
/C1: MX3.1 (COL), SW7.S1, SW8.2, SW9.2, SW10.2, SW11.2, SW12.2, U3.17 (PA7)
/C2: MX4.1 (COL), SW13.S1, SW14.2, SW15.2, SW16.2, SW17.2, SW18.2, U3.43 (PB7)
/C3: MX5.1 (COL), MX6.1 (COL), SW19.2, SW20.2, SW21.2, SW22.2, SW23.2, U3.42 (PB6)
/E1A: RN1.5, RN1.6, SW7.A
/E1B: RN1.7, RN1.8, SW7.B
/E2A: RN2.5, RN2.6, SW13.A
/E2B: RN2.7, RN2.8, SW13.B
/ENC1A_DB: C50.1, RN1.4, U3.25 (PB12)
/ENC1B_DB: C52.1, RN1.1, U3.26 (PB13)
/ENC2A_DB: C51.1, RN2.4, U3.29 (PA8)
/ENC2B_DB: C53.1, RN2.1, U3.30 (PA9)
/LED: Q2.2 (S), R5.2, U3.28 (PB15)
/LED_5V: D2.4 (DIN), Q2.3 (D), R6.2
/L_R1: SW3.3 (DI), SW19.4 (DO)
/L_R2: SW4.3 (DI), SW20.4 (DO)
/L_R3: SW5.3 (DI), SW21.4 (DO)
/L_R4: SW6.3 (DI), SW22.4 (DO)
/R0: D16.1 (K), D24.1 (K), U3.34 (PA13)
/R1: D4.1 (K), D10.1 (K), D18.1 (K), D25.1 (K), U3.27 (PB14)
/R2: D5.1 (K), D11.1 (K), D19.1 (K), D26.1 (K), U3.31 (PA10)
/R3: D6.1 (K), D12.1 (K), D20.1 (K), D27.1 (K), U3.10 (PA0)
/R4: D7.1 (K), D13.1 (K), D21.1 (K), D28.1 (K), U3.12 (PA2)
/R5: D8.1 (K), D14.1 (K), D22.1 (K), D29.1 (K), U3.11 (PA1)
/USB+: J1.A6 (D+), J1.B6 (D+), U2.3 (IO2)
/USB-: J1.A7 (D-), J1.B7 (D-), U2.1 (IO1)
/USB_D+: U2.4 (IO2); also elsewhere on the board
/USB_D-: U2.6 (IO1); also elsewhere on the board
/USB_MCU_D+: U3.33 (PA12); also elsewhere on the board
/USB_MCU_D-: U3.32 (PA11); also elsewhere on the board
GND: C1.2, C4.2, C5.2, C6.2, C7.2, C8.2, C9.2, C10.2, C11.2, C12.2, C13.2, C14.2, C15.2, C16.2, C17.2, C18.2, C19.2, C20.2, C21.2, C22.2, C23.2, C24.2, C25.2, C26.2, C27.2, C28.2, C29.2, C30.2, C31.2, C32.2, C33.2, C34.2, C35.2, C36.2, C37.2, C38.2, C39.2, C40.2, C48.2, C49.2, C50.2, C51.2, C52.2, C53.2, D2.3 (VSS), D3.3 (VSS), D9.3 (VSS), D15.3 (VSS), D17.3 (VSS), D23.3 (VSS), D30.3 (VSS), J1.A1 (GND), J1.A12 (GND), J1.B1 (GND), J1.B12 (GND), J1.S1 (SHIELD), JP1.2, Q1.2 (E), R2.1, R3.1, R4.2, SW2.6 (GND), SW3.6 (GND), SW4.6 (GND), SW5.6 (GND), SW6.6 (GND), SW7.C, SW8.6 (GND), SW9.6 (GND), SW10.6 (GND), SW11.6 (GND), SW12.6 (GND), SW13.C, SW14.6 (GND), SW15.6 (GND), SW16.6 (GND), SW17.6 (GND), SW18.6 (GND), SW19.6 (GND), SW20.6 (GND), SW21.6 (GND), SW22.6 (GND), SW23.6 (GND), U1.2 (GND), U2.2 (GND), U3.8 (VSSA), U3.23 (VSS), U3.35 (VSS), U3.47 (VSS); also elsewhere on the board
unnamed: D1.2 (A), Q1.1 (B), SW1.2
unnamed: D2.2 (DOUT), D3.4 (DIN)
unnamed: D3.2 (DOUT), D9.4 (DIN)
unnamed: D4.2 (A), SW2.1
unnamed: D5.2 (A), MX1.2 (ROW), SW3.1
unnamed: D6.2 (A), SW4.1
unnamed: D7.2 (A), MX2.2 (ROW), SW5.1
unnamed: D8.2 (A), SW6.1
unnamed: D10.2 (A), SW8.1
unnamed: D11.2 (A), SW9.1
unnamed: D12.2 (A), SW10.1
unnamed: D13.2 (A), SW11.1
unnamed: D14.2 (A), MX3.2 (ROW), SW12.1
unnamed: D15.2 (DOUT), D17.4 (DIN)
unnamed: D9.2 (DOUT), D15.4 (DIN)
unnamed: D16.2 (A), SW7.S2
unnamed: D17.2 (DOUT), D23.4 (DIN)
unnamed: D18.2 (A), SW14.1
unnamed: D19.2 (A), SW15.1
unnamed: D20.2 (A), SW16.1
unnamed: D21.2 (A), SW17.1
unnamed: D22.2 (A), MX4.2 (ROW), SW18.1
unnamed: D23.2 (DOUT), D30.4 (DIN)
unnamed: D24.2 (A), SW13.S2
unnamed: D25.2 (A), SW19.1
unnamed: D26.2 (A), MX5.2 (ROW), SW20.1
unnamed: D27.2 (A), SW21.1
unnamed: D28.2 (A), MX6.2 (ROW), SW22.1
unnamed: D29.2 (A), SW23.1
unnamed: D32.1 (K), R14.1
unnamed: J1.A5 (CC1), R2.2
unnamed: J1.B5 (CC2), R3.2
unnamed: JP1.1, R14.2
unnamed: SW2.4 (DO), SW8.3 (DI)
unnamed: SW3.4 (DO), SW9.3 (DI)
unnamed: SW4.4 (DO), SW10.3 (DI)
unnamed: SW10.4 (DO), SW16.3 (DI)
unnamed: SW5.4 (DO), SW11.3 (DI)
unnamed: SW11.4 (DO), SW17.3 (DI)
unnamed: SW6.4 (DO), SW12.3 (DI)
unnamed: SW12.4 (DO), SW18.3 (DI)
unnamed: SW8.4 (DO), SW14.3 (DI)
unnamed: SW14.4 (DO), SW19.3 (DI)
unnamed: SW9.4 (DO), SW15.3 (DI)
unnamed: SW15.4 (DO), SW20.3 (DI)
unnamed: SW16.4 (DO), SW21.3 (DI)
unnamed: SW17.4 (DO), SW22.3 (DI)
unnamed: SW18.4 (DO), SW23.3 (DI)
VBUS: C14.1, F1.2, J1.A4 (VBUS), J1.A9 (VBUS), J1.B4 (VBUS), J1.B9 (VBUS), U2.5 (VBUS)

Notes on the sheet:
Logos / Markings
Mounting Holes
Voltage Regulator
Upstream Connector
Reset
Debounce
Underglow
LED Decoupling
Matrix
Microcontroller
3v3 -> 5V0
SK6812 Mini E's are part of the key switch footprint, so add placeholders for the LEDs themselves. These will generate the correct XY positions for the LEDs when placed upon the MX footprint. It also ensures they show up as a line item on the BOM.

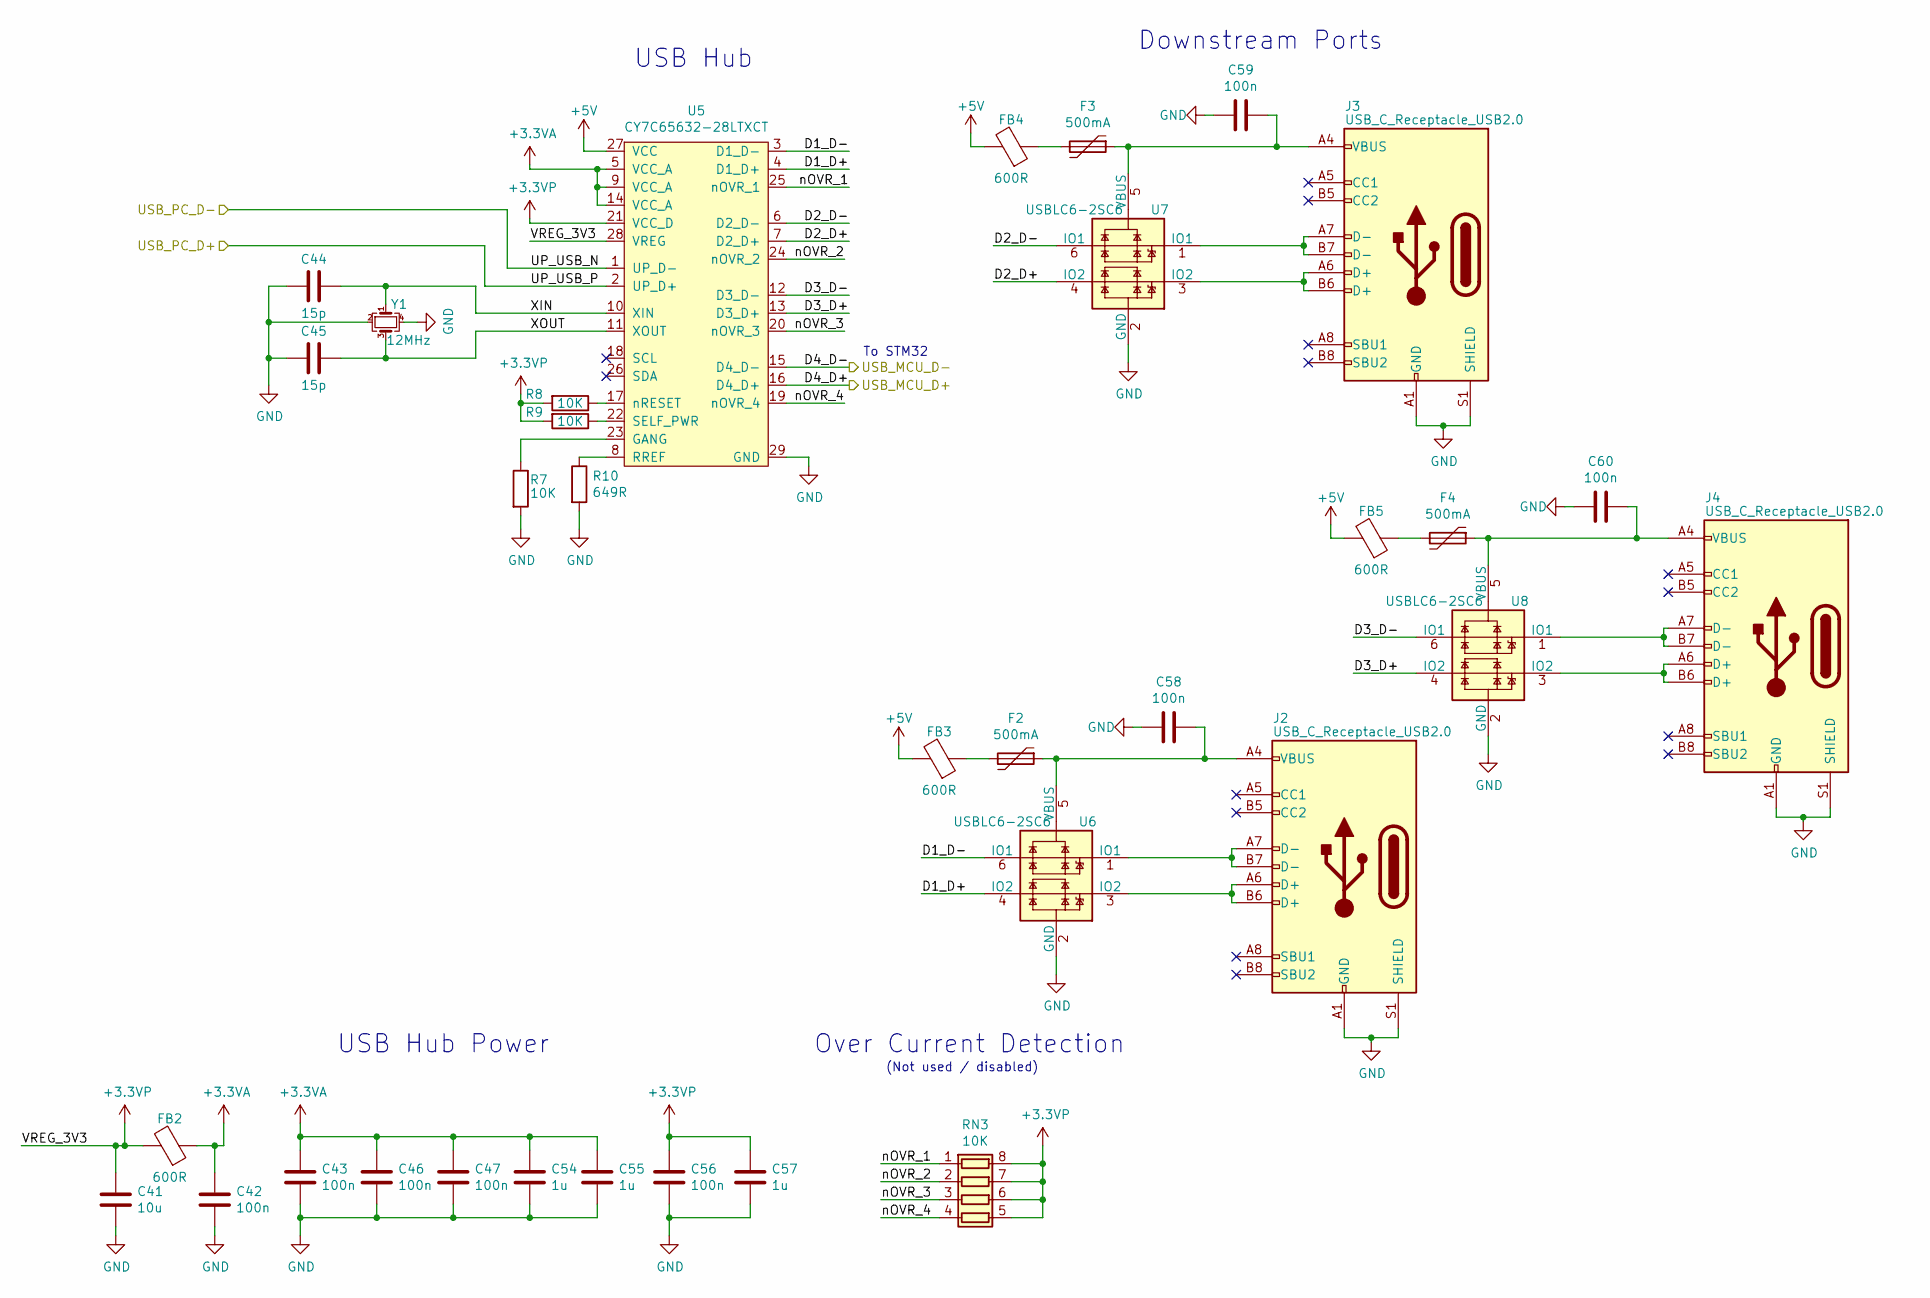
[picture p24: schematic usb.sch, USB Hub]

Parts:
C17, C18: 15p; C_0603_1608Metric; MPN CL10C150JB8NNNC; DigiKey 1276-1296-2-ND
C41: 10u; C_0603_1608Metric; MPN CL10A106MP8NNNC; DigiKey 1276-1871-1-ND
C42, C43, C46, C47, C56, C58, C59, C60: 100n; C_0603_1608Metric; MPN CL10B104KB8NNNC; DigiKey 1276-1000-1-ND
C54, C55, C57: 1u; C_0603_1608Metric; MPN CL10A105MP8NNNC; DigiKey 1276-1866-1-ND
F2, F3, F4: 500mA; Fuse_0805_2012Metric; MPN 0805L050WR; DigiKey F2772CT-ND
FB1, FB2, FB3, FB4: 600R; Ferrite_Bead_0603; MPN BLM18KG601SN1D; LCSC C85833
J2, J3, J4: USB_C_Receptacle_USB2.0; USB_C_U262-161N-4BVC11; MPN U262-161N-4BVC11; LCSC C319148
R7, R8, R9: 10K; R_0603_1608Metric; MPN CR0603-JW-103ELF; DigiKey CR0603-JW-103ELFCT-ND
R10: 649R; R_0603_1608Metric; MPN MCR03ERTF6490; DigiKey RHM649CFCT-ND
RN3: 10K; R_Array_Convex_4x0603; MPN RAVF164DJT10K0; DigiKey RAVF164DJT10K0CT-ND
U5: CY7C65632-28LTXCT; QFN-28-1EP_5x5mm_P0.5mm_EP3.35x3.35mm_ThermalVias; MPN CY7C65632-28LTXCT; LCSC C466886
U6, U7, U8: USBLC6-2SC6; SOT-23-6; MPN USBLC6-2SC6; DigiKey 497-5235-1-ND
Y2: 12MHz; Crystal_SMD_3225-4Pin_3.2x2.5mm; MPN ABM8-12.000MHZ-12-B1U-T; LCSC C164041

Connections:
/USB Hub/D1_D+: U5.4 (D1_D+), U6.4 (IO2)
/USB Hub/D1_D-: U5.3 (D1_D-), U6.6 (IO1)
/USB Hub/D2_D+: U5.7 (D2_D+), U7.4 (IO2)
/USB Hub/D2_D-: U5.6 (D2_D-), U7.6 (IO1)
/USB Hub/D3_D+: U5.13 (D3_D+), U8.4 (IO2)
/USB Hub/D3_D-: U5.12 (D3_D-), U8.6 (IO1)
/USB Hub/nOVR_1: RN3.1 (R1.1), U5.25 (nOVR_1)
/USB Hub/nOVR_2: RN3.2 (R2.1), U5.24 (nOVR_2)
/USB Hub/nOVR_3: RN3.3 (R3.1), U5.20 (nOVR_3)
/USB Hub/nOVR_4: RN3.4 (R4.1), U5.19 (nOVR_4)
/USB_D+: U5.2 (UP_D+); also elsewhere on the board
/USB_D-: U5.1 (UP_D-); also elsewhere on the board
/USB_MCU_D+: U5.16 (D4_D+); also elsewhere on the board
/USB_MCU_D-: U5.15 (D4_D-); also elsewhere on the board
GND: C17.2, C18.2, C41.2, C42.2, C43.2, C46.2, C47.2, C54.2, C55.2, C56.2, C57.2, C58.2, C59.2, C60.2, J2.A1 (GND), J2.A12 (GND), J2.B1 (GND), J2.B12 (GND), J2.S1 (SHIELD), J3.A1 (GND), J3.A12 (GND), J3.B1 (GND), J3.B12 (GND), J3.S1 (SHIELD), J4.A1 (GND), J4.A12 (GND), J4.B1 (GND), J4.B12 (GND), J4.S1 (SHIELD), R7.2, R10.2, U5.29 (GND), U6.2 (GND), U7.2 (GND), U8.2 (GND); also elsewhere on the board
unnamed: C58.1, F2.1, J2.A4 (VBUS), J2.A9 (VBUS), J2.B4 (VBUS), J2.B9 (VBUS), U6.5 (VBUS)
unnamed: C59.1, F3.1, J3.A4 (VBUS), J3.A9 (VBUS), J3.B4 (VBUS), J3.B9 (VBUS), U7.5 (VBUS)
unnamed: C60.1, F4.1, J4.A4 (VBUS), J4.A9 (VBUS), J4.B4 (VBUS), J4.B9 (VBUS), U8.5 (VBUS)
unnamed: F2.2, FB3.1
unnamed: F3.2, FB4.1
unnamed: J2.A6 (D+), J2.B6 (D+), U6.3 (IO2)
unnamed: J2.A7 (D-), J2.B7 (D-), U6.1 (IO1)
unnamed: J3.A6 (D+), J3.B6 (D+), U7.3 (IO2)
unnamed: J3.A7 (D-), J3.B7 (D-), U7.1 (IO1)
unnamed: J4.A6 (D+), J4.B6 (D+), U8.3 (IO2)
unnamed: J4.A7 (D-), J4.B7 (D-), U8.1 (IO1)
unnamed: R7.1, U5.23 (GANG)
unnamed: R8.1, U5.17 (nRESET)
unnamed: R9.1, U5.22 (SELF_PWR)
unnamed: R10.1, U5.8 (RREF)

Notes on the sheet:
USB Hub
USB Hub Power
Over Current Detection
(Not used / disabled)
Downstream Ports
To STM32

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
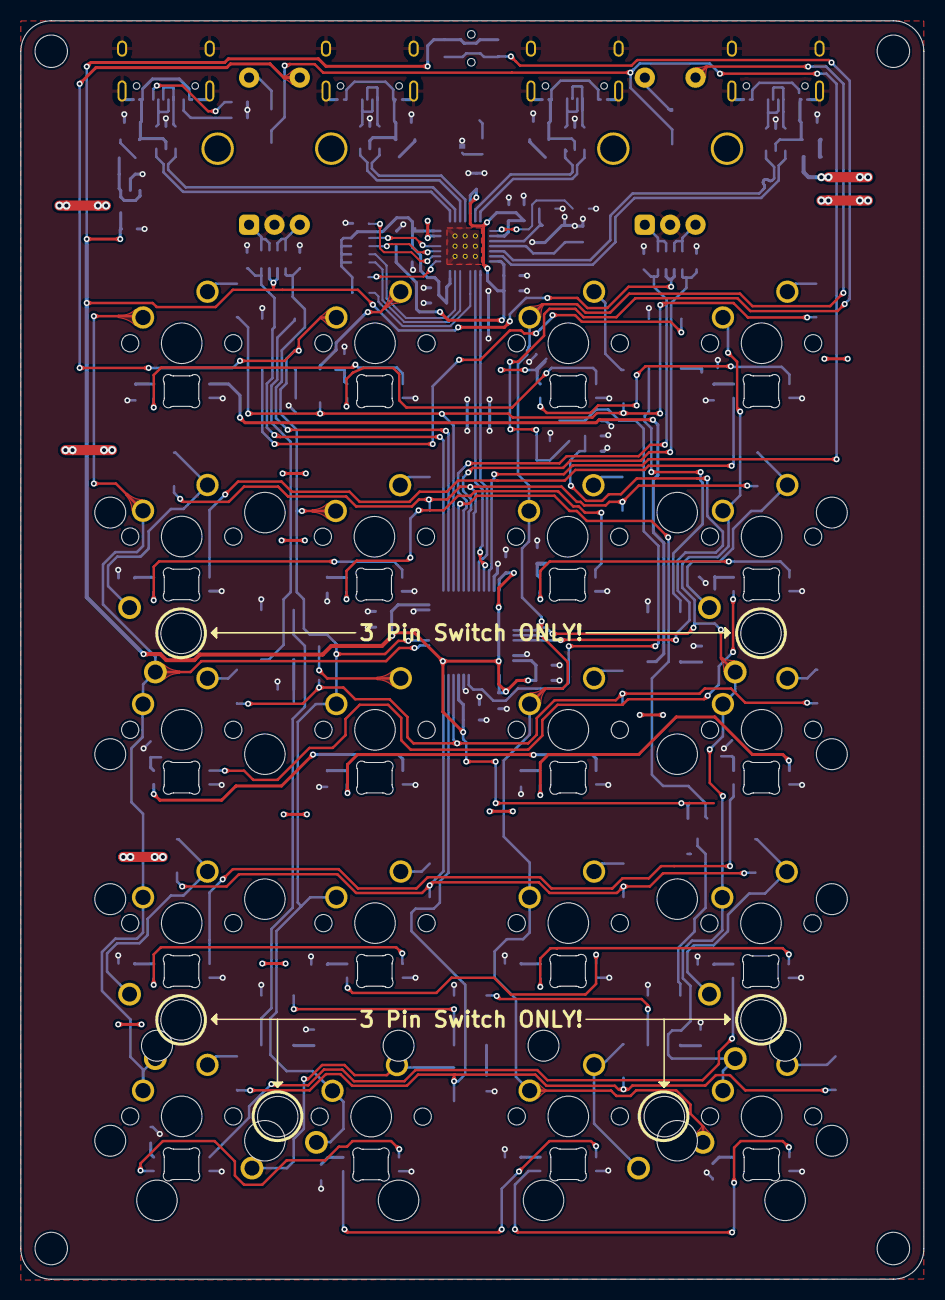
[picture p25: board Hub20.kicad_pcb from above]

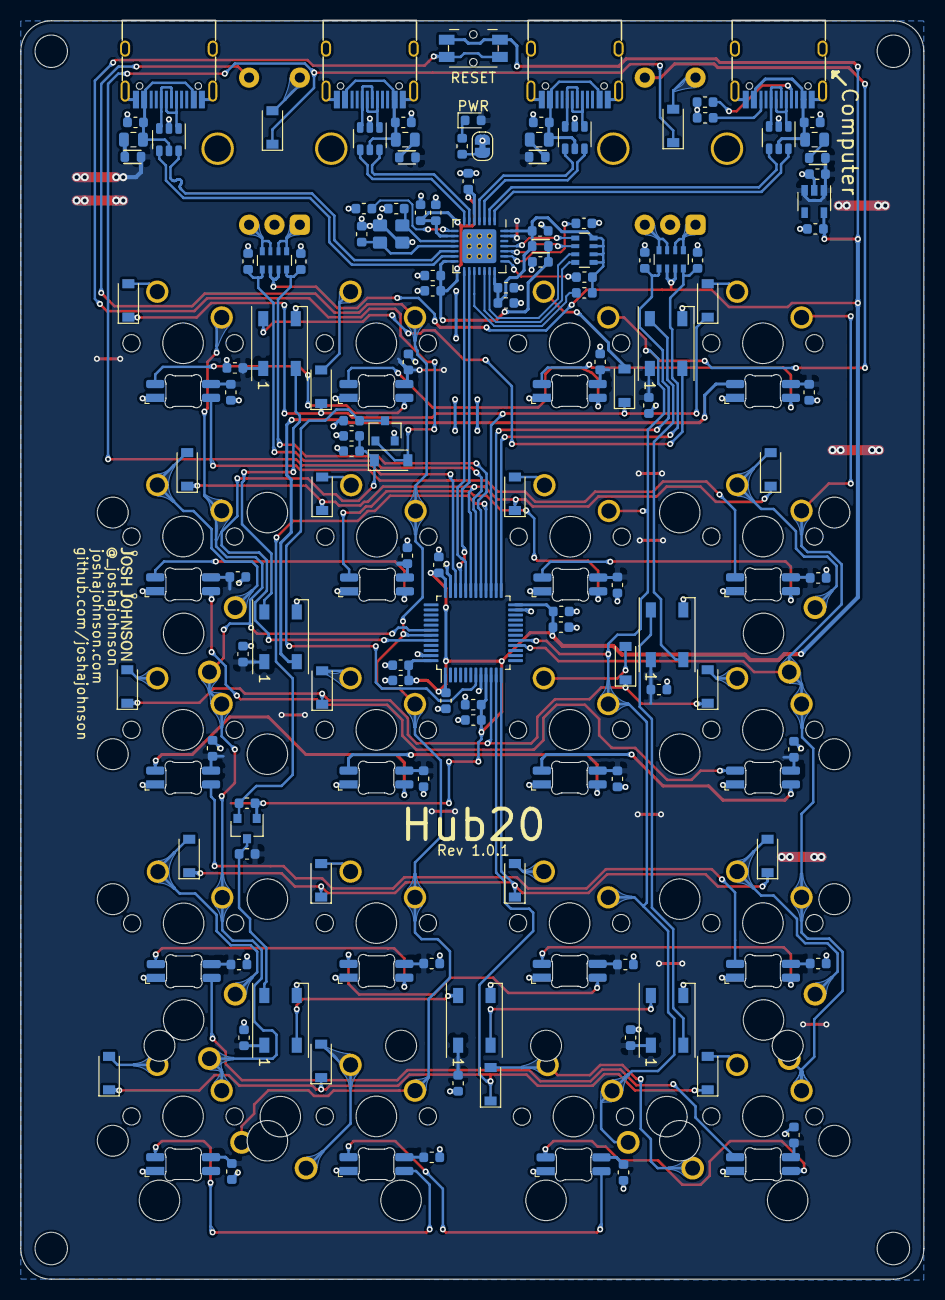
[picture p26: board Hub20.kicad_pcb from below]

Board: 2 copper layers, 89.0 x 124.0 mm, 183 parts (151 on the bottom side), 116 nets.

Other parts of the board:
C44, C45: 15p; C_0603_1608Metric
FB5: 600R; Ferrite_Bead_0603
Y1: 12MHz; Crystal_SMD_3225-4Pin_3.2x2.5mm

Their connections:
GND: C44.2, C45.2, Y1.2, Y1.4; also elsewhere on the board

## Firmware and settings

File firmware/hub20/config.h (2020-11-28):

/*
Copyright 2020 joshajohnson

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
You should have received a copy of the GNU General Public License
along with this program.  If not, see <http://www.gnu.org/licenses/>.
*/

#pragma once

/* USB Device descriptor parameter */
#define VENDOR_ID       0x6A6A  // JJ
#define PRODUCT_ID      0x4414  // H20
#define DEVICE_VER      0x0001
#define MANUFACTURER    joshajohnson
#define PRODUCT         Hub20
#define DESCRIPTION     Numpad with integrated USB Hub and rotary encoders

/* key matrix */
#define MATRIX_ROWS 6
#define MATRIX_COLS 4

#define MATRIX_ROW_PINS { A13, B14, A10, A0, A2, A1 }
#define MATRIX_COL_PINS { A6, A7, B7, B6 }

/* COL2ROW, ROW2COL*/
#define DIODE_DIRECTION COL2ROW

/* Rotary Encoder Things */
// #define ENCODER_DIRECTION_FLIP
#define ENCODERS_PAD_A { B12, A8 }
#define ENCODERS_PAD_B { B13, A9 }

#define RGB_DI_PIN B15
#define RGBLED_NUM 27
#define RGBLIGHT_HUE_STEP 8
#define RGBLIGHT_SAT_STEP 8
#define RGBLIGHT_VAL_STEP 8
#define RGBLIGHT_LIMIT_VAL 255 /* The maximum brightness level */
#define RGBLIGHT_SLEEP         /* If defined, the RGB lighting will be switched off when the host goes to sleep */
// /*== all animations enable ==*/
#define RGBLIGHT_ANIMATIONS
// /*== or choose animations ==*/
// #define RGBLIGHT_EFFECT_BREATHING
// #define RGBLIGHT_EFFECT_RAINBOW_MOOD
// #define RGBLIGHT_EFFECT_RAINBOW_SWIRL
// #define RGBLIGHT_EFFECT_SNAKE
// #define RGBLIGHT_EFFECT_KNIGHT
// #define RGBLIGHT_EFFECT_CHRISTMAS
// #define RGBLIGHT_EFFECT_STATIC_GRADIENT
// #define RGBLIGHT_EFFECT_RGB_TEST
// #define RGBLIGHT_EFFECT_ALTERNATING
// /*== customize breathing effect ==*/
// /*==== (DEFAULT) use fixed table instead of exp() and sin() ====*/
// #define RGBLIGHT_BREATHE_TABLE_SIZE 256      // 256(default) or 128 or 64
// /*==== use exp() and sin() ====*/
// #define RGBLIGHT_EFFECT_BREATHE_CENTER 1.85  // 1 to 2.7
// #define RGBLIGHT_EFFECT_BREATHE_MAX    255   // 0 to 255

/* Debounce reduces chatter (unintended double-presses) - set 0 if debouncing is not needed */
#define DEBOUNCE 5

/* Tap delay for tap vs hold */
#define TAPPING_TERM 200

/* Slow down key press speed to ensure computer picks it up */
#define TAP_CODE_DELAY 20

/* Mechanical locking support. Use KC_LCAP, KC_LNUM or KC_LSCR instead in keymap */
#define LOCKING_SUPPORT_ENABLE
/* Locking resynchronize hack */
#define LOCKING_RESYNC_ENABLE

/* disable these deprecated features by default */
#ifndef LINK_TIME_OPTIMIZATION_ENABLE
  #define NO_ACTION_MACRO
  #define NO_ACTION_FUNCTION
#endif

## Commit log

2020-07-04 clean up routing, design review TODO
    [Hub20.kicad_pcb, Hub20.sch]
2020-07-26 designs off to fab
    [Hub20.kicad_pcb, Hub20.sch, usb.sch]
2020-07-26 fit label locations
    [Hub20.kicad_pcb]
2020-08-08 start 0.2 layout
    [Hub20.kicad_pcb, Hub20.sch, usb.sch]
2020-08-09 layout getting close
    [Hub20.kicad_pcb, Hub20.sch, usb.sch]
2020-08-09 center encoders :/
    [Hub20.kicad_pcb]
2020-08-12 tidy up things
    [Hub20.kicad_pcb, Hub20.sch, usb.sch]
2020-08-12 improved ground return under USB hub
    [Hub20.kicad_pcb]
2020-08-12 now passing DRC
    [Hub20.kicad_pcb]
2020-08-16 side mounted rst + slik cleanup
    [Hub20.kicad_pcb, Hub20.sch]
2020-08-18 update plate
    [Hub20.kicad_pcb]
2020-08-19 stop touching the design josh
    [Hub20.kicad_pcb]
2020-08-19 move plates to mechanicals folder
    [Hub20.kicad_pcb, Hub20.sch, usb.sch]
2020-08-22 update BOM
    [Hub20.kicad_pcb, Hub20.sch, usb.sch]
2020-09-06 limit 2U to 3 pin only
    [Hub20.kicad_pcb, Hub20.sch]
2020-09-09 update fuse values
    [Hub20.sch, usb.sch]
2020-09-14 1.0 production files ready
    [Hub20.kicad_pcb, Hub20.sch, bom.csv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]
2020-09-20 add mechanicals
    [Hub20-bottom.dxf, Hub20-mid.dxf, Hub20-riser.dxf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]
2020-10-10 update test script + enclosure files
2020-11-28 add assembly instructions
2020-11-28 update link to assembly instructions
2020-12-02 typo + fix switch usage
2021-03-21 1.0.1 initial release
    [Hub20.kicad_pcb, Hub20.sch, usb.sch]
2021-06-20 update pcb for production
    [Hub20.kicad_pcb]
2021-06-20 update assembly instructions
2021-06-26 clean up production files
    [Hub20.kicad_pcb, Hub20.sch, bom.csv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]

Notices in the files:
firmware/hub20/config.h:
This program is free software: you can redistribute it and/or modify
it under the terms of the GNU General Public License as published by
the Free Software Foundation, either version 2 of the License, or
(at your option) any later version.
